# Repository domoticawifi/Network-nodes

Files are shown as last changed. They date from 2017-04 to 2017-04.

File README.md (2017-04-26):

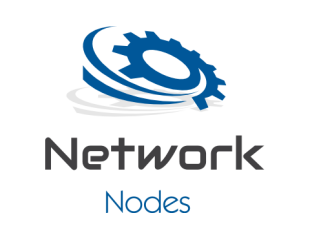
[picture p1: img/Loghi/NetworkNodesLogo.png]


Questo progetto vede la realizzazione, tramite Arduino, di una piccola rete [LAN](https://it.wikipedia.org/wiki/Local_Area_Network) (domestica o aziendale) che permette di far comunicare, attraverso un terminale PC (o qualsiasi altro device connesso alla rete), i nodi della rete; quest'ultimi collegati tra loro attraverso un collegamento ottico(infrarossi).

_____________________________________

#  Indice
* <a href="#ancora-struttura">Struttura</a>
* <a href="#ancora-comunicazioni">Comunicazioni</a>
  * <a href="#ancora-es-comunicazione">Esempio comunicazione</a>
* <a href="#ancora-schemaNet">Schema Network</a>
* <a href="#ancora-occorrente">Occorrente</a>
  * <a href="#ancora-occ-hard">Hardware</a>
  * <a href="#ancora-occ-soft">Software</a>
* <a href="#ancora-faseop">Fase Operativa</a>
  * <a href="#ancora-faseuno">1° Fase</a>
  * <a href="#ancora-fasedue">2° Fase</a>
    * <a href="#ancora-faseduemaster">Nodo Master</a>
    * <a href="#ancora-faseduenoduno">Nodo 1</a>
  * <a href="#ancora-fasetre">3° Fase</a>
    * <a href="#ancora-protuno">Primo Prototipo: Simple Connection</a>
      * <a href="#ancora-protuno-video">Video Dimostrativo Prototipo Uno</a>
    * <a href="#ancora-protdue">Secondo Prototipo: Connected Oriented</a>
        * <a href="#ancora-protdue-sol1">Soluzione "Switch Transistor"</a>
        * <a href="#ancora-protdue-sol2">Soluzione "Sensore Sferico"</a>
          * <a href="#ancora-protdue-video">Video Dimostrativo Prototipo Due</a>
* <a href="#ancora-db">Database</a>
* <a href="#ancora-app">Applicazione Android</a>
* <a href="#ancora-problemi">Problemi Rilevati</a>
* <a href="#ancora-algor">Algoritmi</a>
   * <a href="#ancora-algor-nodomaster">Nodo Master</a>
   * <a href="#ancora-algor-nodo1">Nodo 1</a>
   * <a href="#ancora-algor-nodo2">Nodo 2</a>
* <a href="#ancora-conclcost">Conclusione e Costi</a>

_____________________________________

##  Struttura



Abbiamo presvisto un terminale PC, un Nodo Master e due nodi, schematizzati in questa maniera (classifichiamo questa rete come [P2P](https://it.wikipedia.org/wiki/Peer-to-peer):
  * Terminale (Invia e riceve le informazioni dei nodi attraverso la rete accedendo all'[indirizzo IP](https://it.wikipedia.org/wiki/Indirizzo_IP) del Nodo Master)
  * [Router](https://it.wikipedia.org/wiki/Router) (Instrada le richieste fatte tra terminale e Nodo Master sulla rete domestica e anche quella esterna andando ad aggiornare un [DB](https://it.wikipedia.org/wiki/Base_di_dati))
  * Nodo Master (Nodo formato da un modulo [ESP8266 ESP-12E](https://acrobotic.com/acr-00018) per il collegamento WI-FI con il terminale, l'invio delle informazioni sul DB e la trasmissione di informazioni tra i vari nodi presenti nella rete locale).
  * Nodo1 (Nodo formato da [Arduino NANO](https://www.arduino.cc/en/Main/arduinoBoardNano) che gestisce un attuatore/relè/led e, in futuro, un eventuale sensore)
  * Nodo2(Stessa cosa del nodo precedente)
  
  *N.B: Lo storage delle informazioni su un DB, ci serve per cotrollare lo stato della rete, anche da smartphone o tablet, in         remoto (Internetworking: il router fungerà da gateway).
  Il Nodo Master può essere, a sua volta, provvisto di attuatori e sensori.
  Il problema della scheda ESP-12E è la scarsità di PIN disponibili: nel nostro caso è sato possibile collegare un solo attuatore/relè a tale nodo a differenza dei due collegati sugli altri nodi.
  La comunicazione otttica tra i nodi è di tipo punto-punto mentre quella LAN (WLAN) è di tipo [broadcast](https://it.wikipedia.org/wiki/Broadcasting_(informatica)).*
  
____________________________________________________________________________________________  
# Comunicazioni  
La comunicazione fra i nodi e il terminale avviene in questa maniera:
  * Il terminale comunica con il solo Nodo Master tramite la rete WI-FI, e riceve ed invia a questo nodo le richieste da fare agli altri due nodi della rete.
  * Il Nodo Master comunica con il terminale, via WI-FI, e, con il Nodo1, attraverso un collegamento ottico (LED IR e Sensor IR), e la stessa comunicazione avviene tra il Nodo1 e Nodo2
  * Ogni nodo può comunicare solamente con il suo nodo adiacente formando un ponte di nodi
  * Se il terminale deve contattare il Nodo2, la sua richiesta passerà prima a tutti i nodi
  
## Esempio di comunicazione: Connected Oriented

## Terminale > Nodo Master > Nodo Interessato
* Attraverso una pagina HTML, appositamente caricata in locale attraverso la scheda Wi-Fi, avremo la possibilità di inviare informazioni alla shield da qualsiasi terminale noi vogliamo (es. PC, smartphone, tablet); inoltre dalla stessa pagina sarà possibile reperire lo stato di ogni nodo(attuatori ON/OFF e sensori)
* Se volessimo inviare una certa informazione, come ad esempio l'accensione o lo spegnimento di un LED(Attuatore e/o Relè), non dovremmo far altro che selezionare l'apposito 'Radio Button' per poi determinare l'invio della Form attraverso il Bottone 'Invio'
* In questa maniera verrà mandata una richiesta tramite rete WI-FI al Nodo Master gestito dalla scheda ESP8266
* La scheda Wi-Fi riceverà la richiesta, la inoltrerà, tramite segnale infrarossi, al nodo adiacente(Nodo 1)
* Il nodo adiacente(Nodo 1) riceve questo segnale e lo elabora per capire se è lui il destinatario
* Se così non fosse lo manda all'altro nodo adiacente(Nodo 2) con il collegamento ottico
* Quando il messaggio è arrivato a destinazione, la scheda arduino presente su tale nodo spegnerà/accenderà l'attuatore o relè
* Verrà mandato, in ritorno, l'avvenuta/o accensione/spegnimento
* Il messaggio di ritorno arriverà fino al Nodo Master che darà in risposta al PC un'altra pagina HTML aggiornata
* Il Nodo Master, successivamente, manderà questo dato sul database per poterlo consultare in remoto tramite smartphone
* Il PC riceverà la pagina HTML aggiornata e vedrà lo stato attuale di tutti i nodi per una prossima operazione  
## Nodo Master > Nodo Interessato
* Il Nodo Master avrà un proprio indirizzo IP nella rete (es: 192.168.1.100)
* Il Nodo Master riceve la richiesta dal PC da instradare al giusto nodo
* Il Nodo Master comunicherà con il Nodo1, essendo il suo adiacente
* Verrà mandato un segnale ottico al Nodo1 con il dato da elaborare
* Il Nodo1 riceve questo dato e lo elabora; una volta elaborato restituisce un [ACK](https://it.wikipedia.org/wiki/ACK_(informatica)) al Nodo Master
* Il Nodo Master chiude la comunicazione
* Il Nodo1 se dovesse ricevere un dato corrotto richiede il rinvio del dato
* Il Nodo1 elabora il dato ricevuto e capisce se appartiene a lui altrimenti lo manda, alla stessa maniera della prima comunicazione, al nodo adiacente (Nodo2)
* Così come il Nodo1 ha elaborato il dato all'andata, il Nodo Master lo farà per il ritorno
* Una volta chiusa la comunicazione il Nodo Master aggiorna la pagina HTML e comunica il cambiamento al database

*N.B: Se non dovesse esserci instradamento in uscita(connessione internet) sulla rete LAN, la connessione tra i nodi non ne risentirebbe e continuerebbe ad operare. Il database verrà aggiornato appena sarà presente una connessione in uscita.
Per verificare lo stato di ogni nodo, si è pensato di collegare un Display LCD o OLED. Su questo display compariranno le azioni che sta eseguendo tale nodo. Esempio: Nodo1 - Display (Sto comunicando...) -> Nodo2 - Display (Sto ricevendo...)*

___________________________________________________________________________________
# Schema Network
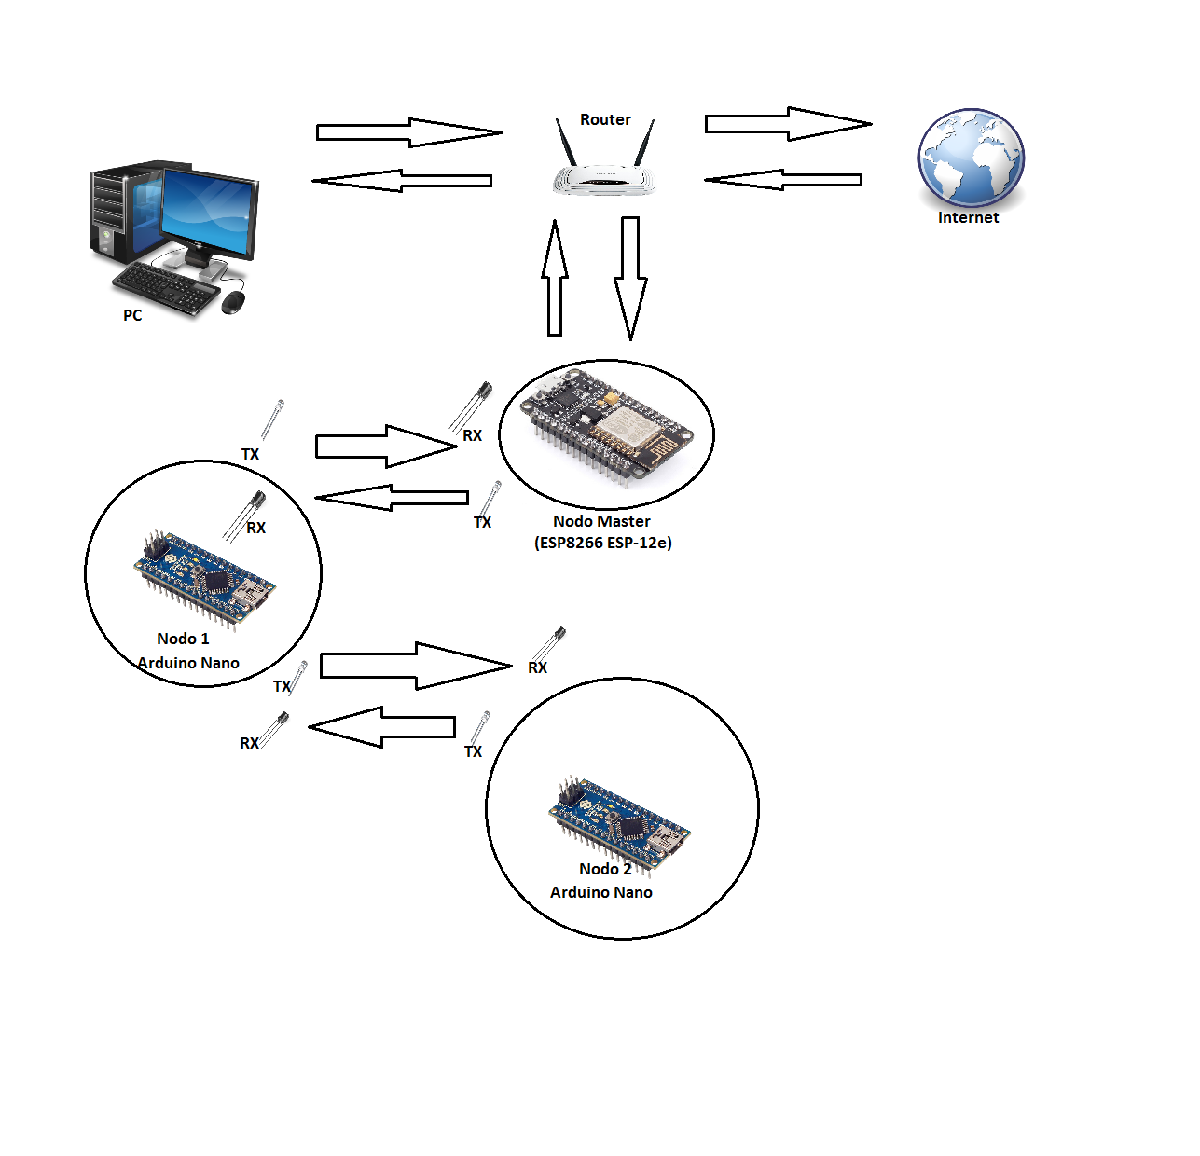
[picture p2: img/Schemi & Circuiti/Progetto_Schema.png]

Come possiamo vedere dall'immagine, abbiamo un PC che funziona da terminale:collegato alla rete WI-FI, invia e riceve informazioni attraverso il Nodo Master.
Il Nodo Master, collegato alla rete, instrada le richieste e le informazioni, mandate dal terminale e dagli altri nodi, nella giusta direzione.

## Occorrente Hardware
  * 1 terminale (PC, Tablet, Smartphone)
  * 1 Router WI-FI
  * 1 ESP8266 ESP-12E oppure una qualsiasi shield WI-FI
  * 2 Arduino NANO/UNO/MEGA/Mino PRO
  * 4 TX Diodo LED infrarossi
  * 4 RX Sensori IR
  * 3 Breadboard (830 fori)
  * Cavetti e jumper per i collegamenti
  * 3 Display LCD per verificare lo stato di ogni nodo
  * 4 pulsanti
  
## Occorrente Software
  * [Arduino IDE 1.8.0](https://www.arduino.cc/en/main/software) o superiori
  * [Firebase](https://firebase.google.com/)
  * [Core ESP8266](https://github.com/domoticawifi/Network-nodes/blob/master/GestioneShieldESP8266.md)
  * [Librearia gestione ESP8266](https://github.com/googlesamples/firebase-arduino/archive/master.zip)
  * [Libreria gestione segnale IR](https://www.pjrc.com/teensy/arduino_libraries/IRremote.zip)
  * [Libreria gestione Display LCD](https://www.dropbox.com/s/62x4w48kwf5biko/LiquidCrystalI2C.zip?dl=0)
  
Per l'installazione e la gestione delle librerie clicca [QUI](https://github.com/domoticawifi/Network-nodes/blob/master/Library/GestioneLibraryArduino.md)

________________________________________________________________________________________  
  
# Fase Operativa

 ## Prima fase: Collegamento Scheda WI-FI ad una rete LAN 
 
 
 
 Potete vedere la connessione Wi-Fi della shield cliccando <a href="https://github.com/domoticawifi/Network-nodes/blob/master/GestioneShieldESP8266.md#ancora-collegamento-wifi">QUI</a>.
 
 * Una volta testata la connessione di questa shield, si è implementata un'interfaccia grafica in HTML per comunicare i cambiamenti di stati di alcuni attuatori e relè presenti sul Nodo Master (attuatori e relè sono sostituiti da semplici led per facilitare i collegamenti, ma il concetto non cambia).
 * La pagina HTML viene mandata al terminale dalla scheda ESP8266 e aggiornata ogni qual volta avviene un cambiamento di stato dettato dal terminale.
 * Il cambiamento di stato avviene attraverso una semplice FORM HTML che invia i dati cambiati all'URL della pagina.
 Ecco la pagina HTML con la relativa Form:
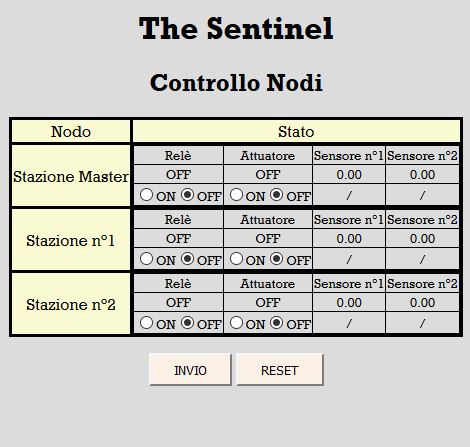
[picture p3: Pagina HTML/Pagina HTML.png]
 
 
*N.B:La pagina HTML ha tutte le funzionalità! Ma di queste solo l'accensione del relè e dell'attuatore sul Nodo Master funziona! Il resto verrà implementato man mano...*
 
 * Il terminale, per accedere a tale pagina HTML, dovrà allocarsi, tramite browser(Chrome, Firefox, Edge, ....) all'indirizzo IP associato alla shield Wi-Fi.
 * Tale indirizzo sarà visualizzato su terminale, per le prime prove, e, in un secondo momento, su un display posizionato sul nodo.
 * Il programma di lancio lo trovate [Qui](https://github.com/domoticawifi/Network-nodes/blob/master/Sketch/Sketch%20Di%20Prova/sketch_SchedaWiFi_NodoMaster_Prova_AccensioneLED.ino).
 
Ecco i collegamenti:
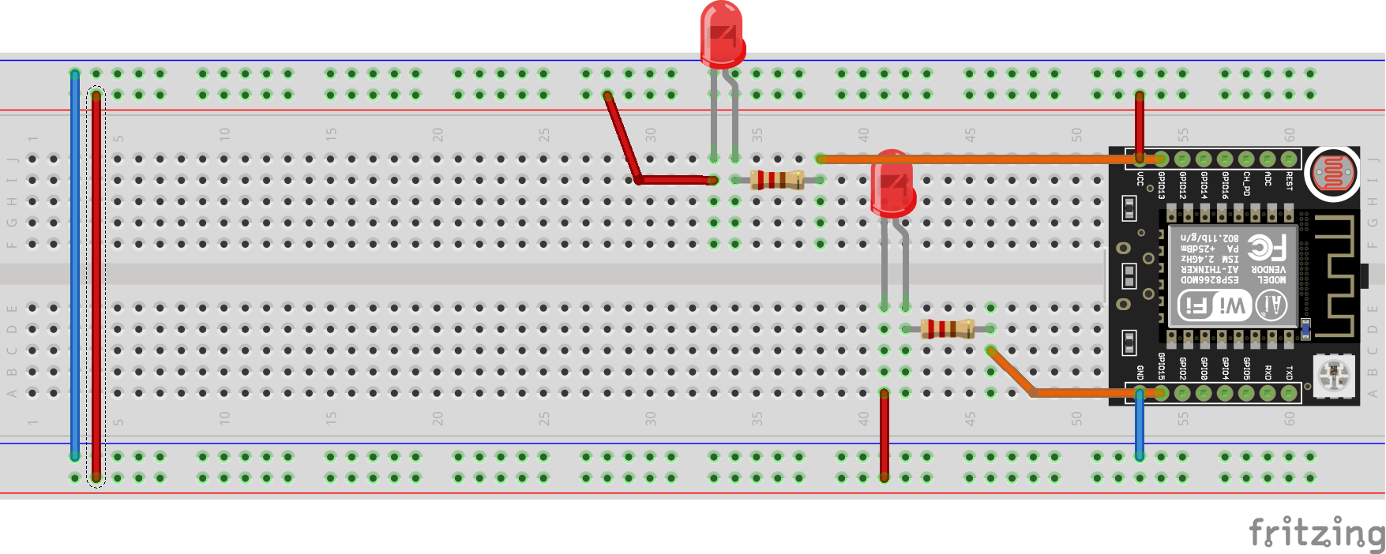
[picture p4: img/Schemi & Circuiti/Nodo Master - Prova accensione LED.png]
 
 Su Fritzing non è presente l'ESP-12E compreso di basetta per i collegamenti e USB incorporata, ma una semplice ESP-12E.
 Con un pò di fantasia immaginiamo che questa scheda sia quella che stiamo utilizzando noi(la scheda con 30 pin), per facilitarne la spiegazione.
 
 I due collegamenti che vanno ai led sono i pin D1 e D2.
 
 *N.B: Nella seconda fase lasceremo solo un led che rappresenterà un solo relè/attuatore, perchè abbiamo poca disponibilità di piedini nella ESP-12E. In questo caso il led sarà collegato al piedino D4; i piedini D1 e D2 saranno riservati al display lcd I2C.*
 
 Ecco una foto dei collegamenti su breadbord:
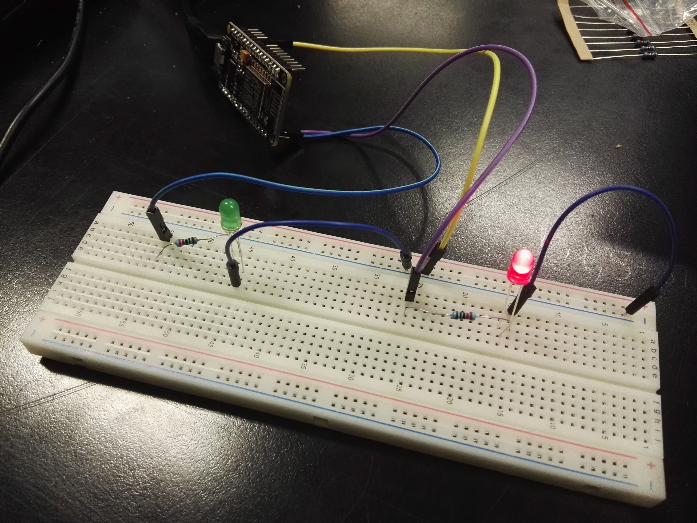
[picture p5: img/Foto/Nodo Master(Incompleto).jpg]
 
 Purtroppo la shield Wi-Fi ha una larghezza che va ha coprire tutta la breadbord e per facilitare i collegamneti abbiamo utilizzato dei jumper.
 Dalla foto risulta acceso il led 2, questo perchè abbiamo attivato, attraverso la pagina HTML visualizzata dal PC, l'accensione del led 2(Che rappresenta un semplice relè).

 Fatto questo possiamo passare ad aggiungere una coppia di LED infrarossi-Ricevitore IR, per la comunicazione ottica con il Nodo 1.

 *N.B: Possiamo anche non utilizzare i resistori, perchè la tensione di uscita sui pin non supera i 3volt.*

 ## Seconda fase: Collegamento Ottico Nodo Master -> Nodo 1 
 
 Per questa fase, avremo la comunicazione fra due nodi, quindi dividiamola, per semplicità, in due sotto-fasi.
 
 ### *Nodo Master: Collegamento Ottico*
 Lo schema che andremo a realizzare sarà il seguente:
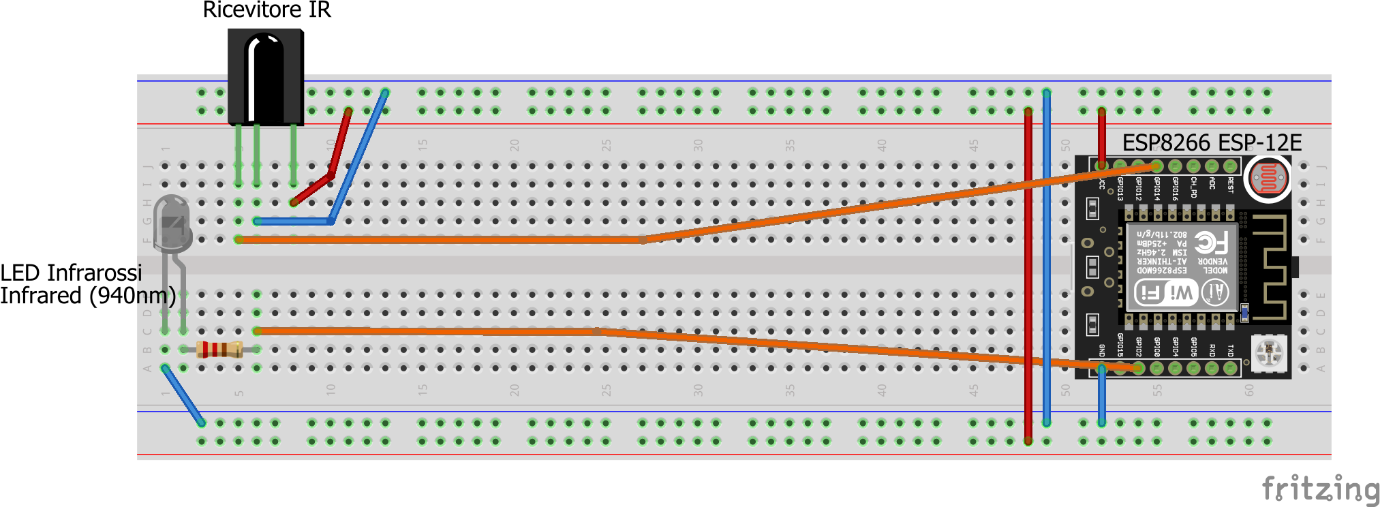
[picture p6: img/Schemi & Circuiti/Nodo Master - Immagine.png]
 
 
 Tale schema dovrà essere incorporato con lo schema della prima fase; così facendo avremmo il nostro Nodo Master completo!
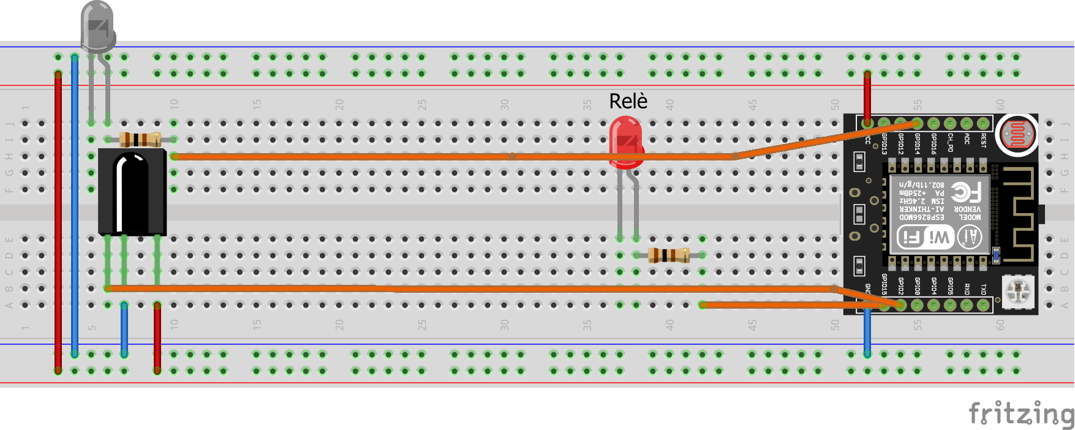
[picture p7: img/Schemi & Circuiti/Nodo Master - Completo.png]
 
 
 I collegamenti sono i seguenti:
 <table align='center'>
  <tr align='center'>
   <td> </td>
   <td>DISPLAY</td>
   <td>LED</td>
   <td>EMETTITORE IR</td>
   <td>RICEVITORE IR</td>
  </tr>
  <tr align='center'>
   <td>ESP8266</td>
   <td>D1, D2</td>
   <td>D4</td>
   <td>D0</td>
   <td>D3</td>
   </tr>
 </table>
 
 Così facendo occuperemo tutti i pin disponibili.
 Purtroppo ESP-12E non ha tanti pin da poter essere utilizzati, perchè gli altri sono tutti gestiti dalla scheda stessa.
  
 Per connettere la scheda al display LCD, vi rimando a [questa pagina](https://www.losant.com/blog/how-to-connect-lcd-esp8266-nodemcu).
 
 *N.B: Possiamo anche non utilizzare i resistori, perchè la tensione di uscita sui pin non supera i 3volt. Se dovessimo usare resistenze alte la luce risulterebbe più fievole, comportando un possibile ostacolo alla comunicazione*
 
 *Durante i collegamneti e i test abbiamo riscontrato un problema! Non sappiamo a cosa sia dovuto, ma se dovessimo alimentare il sensore IR con i 5v della shield Wi-Fi, i dati risulterebbero molto corrotti! Utilizzando l'alimentazione di Arduino i risultati sono migliori... comunque abbiamo dei piccoli problemi, dovuti a disturbi e alla scarsa schermatura, nel rilevare il valore dal sensore. Spiegheremo questo più avanti...*

 Da aggiungere all'occorrente software, per la realizzazione del Nodo Master, è la libreria per la gestione dei segnali infrarossi per la shield ESP8266 (purtroppo non può essere utilizzata la stessa libreria di arduino!).
 Possiamo scaricarla da [qui](https://github.com/markszabo/IRremoteESP8266/), dove è presente una piccola guida per l'installazione.

 ### *Nodo 1: Collegamento Ottico*
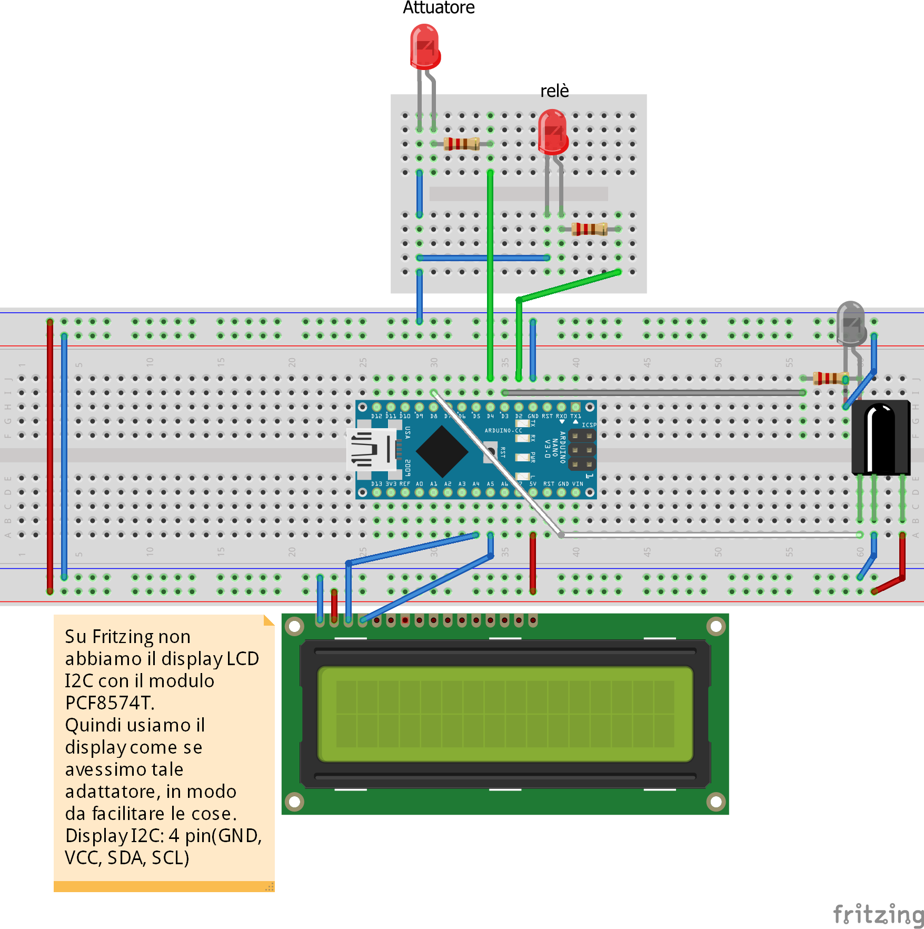
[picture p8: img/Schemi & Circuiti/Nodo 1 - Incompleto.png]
 
 
 *N.B:Può essere usato, tranquillamente, Arduino UNO! Arduino Nano è esattamente uguale(tranne nella dimensione) ad Arduino UNO! Noi per le prove abbiamo utilizzato Arduino UNO per comodità...*
 
 Connessioni:
 
 <table>
 <tr align='center'>
  <td>Arduino UNO/NANO</td>
  <td> </td>
 </tr>
 <tr>
  <td>PIN 2</td>
  <td>Relè</td>
 </tr>
 <tr>
  <td>PIN 3 </td>
  <td>Emettitore LED IR</td>
 </tr>
 <tr>
  <td>PIN 4 </td>
  <td>Attuatore</td>
 </tr>
 <tr>
  <td>PIN 8 </td>
  <td>Ricevitore IR</td>
 </tr>
 <tr>
  <td>PIN A4 </td>
  <td>Display SDA</td>
 </tr>
 <tr>
  <td>PIN A5 </td>
  <td>Display SCL</td>
 </tr>
 <tr>
  <td>5v </td>
  <td>Breadboard</td>
 </tr>
 <tr>
  <td>GND </td>
  <td>Breadboard</td>
 </tr>
</table>

Il collegamento dell'emettitore IR è obbligatorio farlo sul PIN3! Perchè la libreria di Arduino sull'invio del segnare infrarosso utilizza quel piedino per default. Se volessimo cambiare piedino dovremmo andare ad agire sulla libreria.

 Per le prime prove, si è installato, sui due nodi, un emettitore(sul Nodo Master) e un sensore infrarossi(sul Nodo 1), per un semplice test di comunicazione.
 Si è inviato un piccolo dato, sottoforma di codifica NEC, dal Nodo Master al Nodo 1. Si hanno a disposizione tanti tipi di codifica: NEC, Sony, Sharp e tante altre...
 
 Nel nostro caso, ogni nodo avrà almeno una coppia led-sensore per l'invio e ricezione infrarossi, quindi il procedimento è più complesso.
 Il punto che va a favore è che si conosce il dato che potrebbe arrivare, questo perchè possono verificarsi solo queste situazioni:
 * Attivazione Relè Nodo 1;
 * Attivazione Attuatore Nodo 1;
 * Attivazione Relè Nodo 2;
 * Attivazione Attuatore Nodo 2.
 
Quindi i segnali che possono essere inoltrati dall'emettitore IR(sul Nodo Master) sono essenzialmente 4; a questi c'è da aggiungere un solo segnale di ritorno(Nodo 1, Nodo 2) che verifica la corretta ricezione del dato.

Procediamo per gradi...

* Il Nodo 1 riceve un dato dal Nodo Master attraverso la comunicazione infrarossi;
* Il Nodo Master, una volta inviato il dato, rimane in ascolto per l'ok(ACK);
* Il Nodo 1 elabora tale dato e verifica se può usarlo;
* Se può usarlo, lo elabora ed esegue un comando. Fatto questo manda l'ok al Nodo Master;
* Se non può usarlo manda al Nodo Master un dato per il rinvio del dato(il dato potrebbe essere corrotto);
* Il Nodo Master, in base alla risposta del Nodo 1, ritrasmette il dato oppure chiude la comunicazione.

Tutto questo dovrà essere implementato con un elegante e bell'algoritmo. 



Questo è l'algoritmo che dovrà eseguire il Nodo Master una volta inviato il dato.
Il Nodo 1 dovrè elaborare il dato inviato e mandargli la conferma.



*N.B: Se dovesse passare un certo lasso di tempo(es. 10 secondi) la comunicazione si interrompe!*

Una volta eseguiti tutti i collegamenti, possiamo eseguire gli sketch dei due nodi:
* [Programma Nodo Master](https://github.com/domoticawifi/Network-nodes/blob/master/Sketch/Sketch%20Definitivi/Nodo%20Master(Comunicazione%201%20Nodo).ino)
* [Programma Nodo 1](https://github.com/domoticawifi/Network-nodes/blob/master/Sketch/Sketch%20Definitivi/Nodo%201%20-%20Comunicazione%201%20Nodo.ino)

*N.B: Questi due programmi sono per la comunicazione fra Nodo Master e Nodo 1. Se dovessimo collegare un altro nodo(come faremo più in la) i due programmi cambieranno(cambierà solo il programma del Nodo 1).*

Con il lancio di questi due programmi otteniamo il risultato voluto:
* Il client si connette all'indirizzo IP della scheda wi-fi;
* Decide di cambiare lo stato di un attuatore e/o relè sul Nodo 1; 
* Il Nodo Master riceve il dato inviato e lo elabora inviandolo al Nodo 1;
* Il Nodo 1 elabora il dato ricevuto; in questa fase il Nodo Master rimane in ascolto per 10 secondi;
* Il Nodo 1, se accetta il dato, manda un ACK al Nodo Master;
* Il Nodo Master riceve l'ok è chiude la comunicazione aggiornando la pagina HTML che visualizzerà il client.

Il compito del Nodo Master è quello di un server web e di un "Ponte di comunicazione" tra il terminale e gli altri nodi.

*N.B: Potrebbe capitare che:*
* *La comunicazione sia interrotta da un ostacolo:in questo caso il Nodo Master invia per 10 secondi lo stesso dato fino a che non riceverà conferma. Se non dovesse ricevere conferma chiude comunicazione e la pagina HTML non viene aggiornata*
* *La comunicazione viene interrotta solo dopo che il Nodo 1 ha ricevuto il dato corretto(in questo caso non potrà comunicare l'ok):*
*Potremmo risolvere questo problema mandando in ritorno una pagina con un WARNING di comunicazione attraverso un javascript.
Purtroppo non possiamo prevenire ostacoli durante la comunicazione, ma su 100 comunicazione provate, solamente un 10%, non ha ricevuto l'ACK dal Nodo 1!
Mandando il WARNING il client sa che qualcosa non è andato nel modo giusto, perchè potrebbe risultare anche un guasto a qualche componente di comunicazione.
Questo problema potrebbe essere in parte gestito...
Si è pensato di mandare, attraverso il Nodo Master, lo stato precedente del dato che non è stato ricevuto; così facendo si ha la sicurezza, in parte, di far tornare il Nodo 1 allo stato precedente. Questo è possibile se e solo se la comunicazione è interrotta solo nella ricezione della risposta e non nell'invio del dato!*

*PS:
Durante la fase di ascolto del Nodo Master, il Nodo 1 manda un ACK per circa 10 secondi; nei dieci secondi di ascolto, da parte del Nodo Master, vengono prelevati valori random non inviati dal Nodo 1. 
Fortunatamente, nell'arco dei 10 secondi di ascolto, il dato, inviato dal Nodo 1, viene letto dal Nodo Master ricevendo l'ok di avvenuta ricezione.*

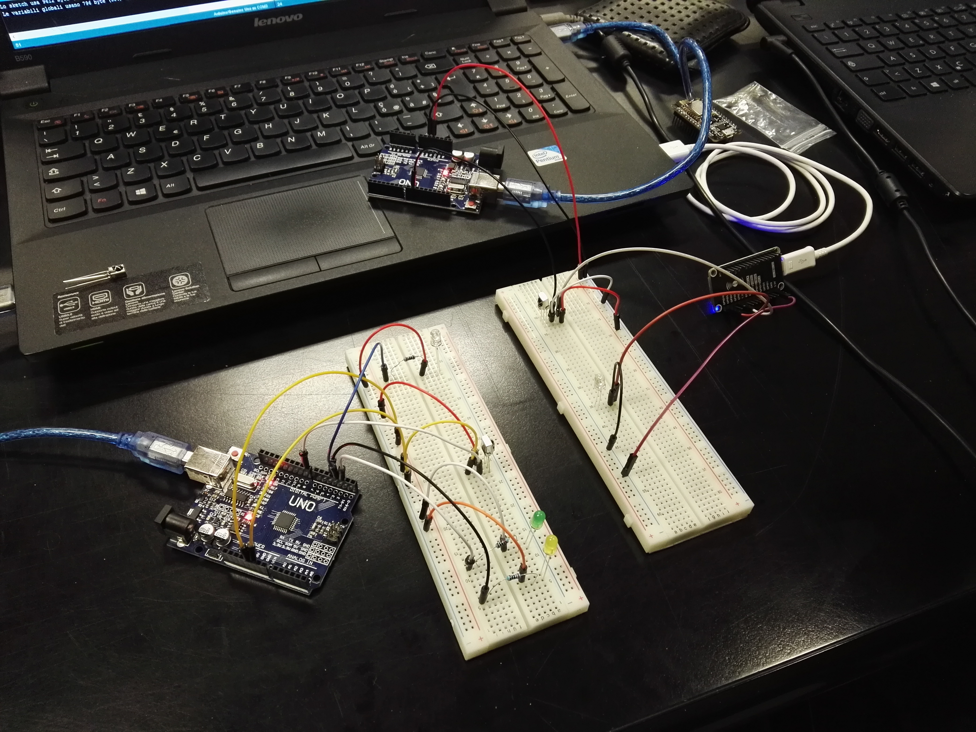
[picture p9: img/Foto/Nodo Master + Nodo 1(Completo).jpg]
</a>

Come dicevamo in precedenza: il terzo arduino serve solo per alimentare il ricevitore del Nodo Master e in secondo a prelevare i valori del sensore, solamente per essere testati.

Il ricevitore IR, del Nodo Master, ci ha dato parecchi problemi:
* I valori rilevati erano falsati(riceveva valori anche quando non venivano inviati segnali infrarossi)
* L'alimentazione della shield Wi-Fi dava parecchi problemi al sensore durante la lettura

##### *Come si è risolto tutto ciò?*
Si è utilizzata, prima di tutto, un'alimentazione esterna, presa da un altro Arduino UNO (l'alimentazione può essere presa anche da una pila esterna), risolvendo in parte i problemi di lettura del sensore; in questo modo parte del primo problema è stata risolta, ma tuttavia continua, in modo random, a ricevere valori casuali.
Non si è venuto a capo di questo!!!
Si è cercato di risolvere la cosa nel migliore dei modi: Potrebbe essere un problema della scheda, un problema del sensore, un problema di alimentazione... Potrebbe essere tutto o niente... 

*N.B: potrebbe capitare che il dato inviato dal Nodo 1 non venga letto del sensore del Nodo Master, ma su 100 prove non è mai successo! Il dato prima o poi verrà letto!*

 ## Terza fase: Collegamento Ottico Nodo Master -> Nodo 1 -> Nodo 2
 Per questa terza fase implementiamo due prototipi:il primo avrà una semplice comunicazione senza risposta del Nodo 2(cioè senza verificare la ricezione del dato), mentre il secondo sarà quello più completo e strutturato in cui anche il Nodo 2 interagisce attraverso l'architettura "Connected Oriented" sfruttata già dagli altri due nodi.
 
 ### *Primo prototipo: Simple Connection*
 * Lo schema per il Nodo Master rimane lo stesso, senza nessuna variazione neanche nel codice(essendo già tutta implementata)
 * Lo schema del Nodo 1 subische piccolissime variazioni(un'aggiunta di un solo LED infrarossi e due pulsanti per l'accensione dei dispositivi):
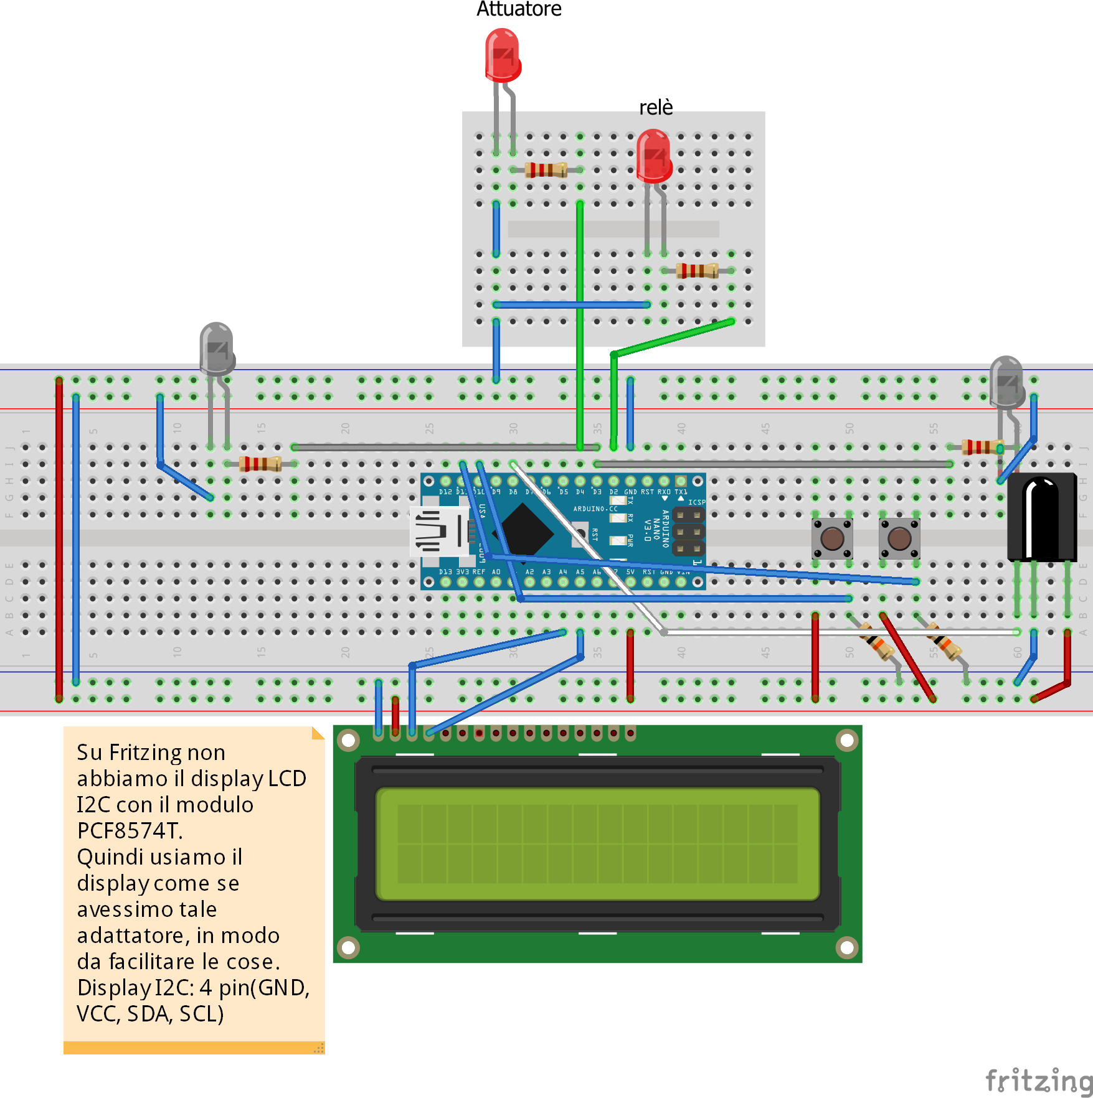
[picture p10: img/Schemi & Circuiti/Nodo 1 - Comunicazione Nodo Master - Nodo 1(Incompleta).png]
 
 
Si è semplicemente aggiunto un altro diodo led infrarossi per inviare il segnale al Nodo 2.
In questo caso abbiamo il LED IR aggiuntivo collegato allo stesso piedino del primo LED IR(in modo da sfruttare la libreria per l'invio del segnale IR, questo perchè, come dicevamo, la libreria IRremote utilizza, per default, il PIN3 di arduino).
Il codice sorgente è leggermente diverso rispetto al primo.
Lo sketch lo trovate [qui](https://github.com/domoticawifi/Network-nodes/blob/master/Sketch/Sketch%20Definitivi/Nodo_1%20-%20Comunicazione%20Nodo%20Master%20e%20Nodo%201.ino).

Si sono aggiunti due pulsanti per controllare, in modo analogico, lo stato dei sispositivi collegati al Nodo 1.
Una volta avvenuto il cambiamento viene comunicato lo stato al Nodo Master.

* Lo schema del Nodo 2 è il seguente:
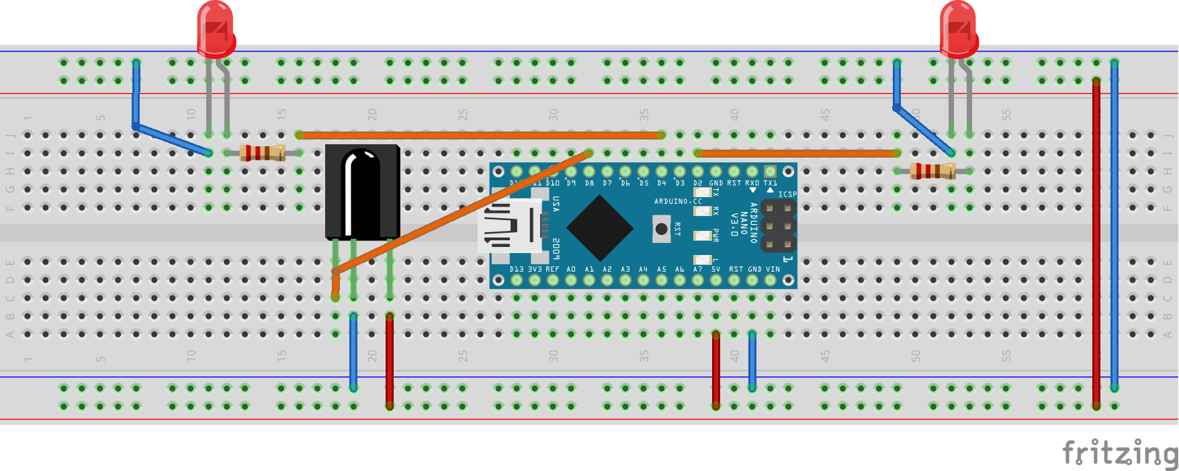
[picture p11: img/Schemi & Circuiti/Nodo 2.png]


I collegamenti:
<table>
 <tr>
 <td>Arduino NANO</td>
 <td> </td>
 </tr>
 <tr>
 <td>PIN 2</td>
 <td>LED(Relay)</td>
 </tr>
 <tr>
 <td>PIN 4</td>
 <td>LED(Attuatore)</td>
 </tr>
 <tr>
 <td>PIN 8</td>
 <td>Ricevitore IR</td> 
 </tr>
 <tr>
 <td>PIN A4</td>
 <td>Display SDA</td> 
 </tr>
 <tr>
 <td>PIN A5</td>
 <td>Display SCL</td> 
 </tr>
</table>

Lo sketch da far eseguire a questa scheda è il [seguente](https://github.com/domoticawifi/Network-nodes/blob/master/Sketch/Sketch%20Definitivi/Nodo_2%20-%20Incompleto.ino)

La disposizione dei tre nodi è il seguente:
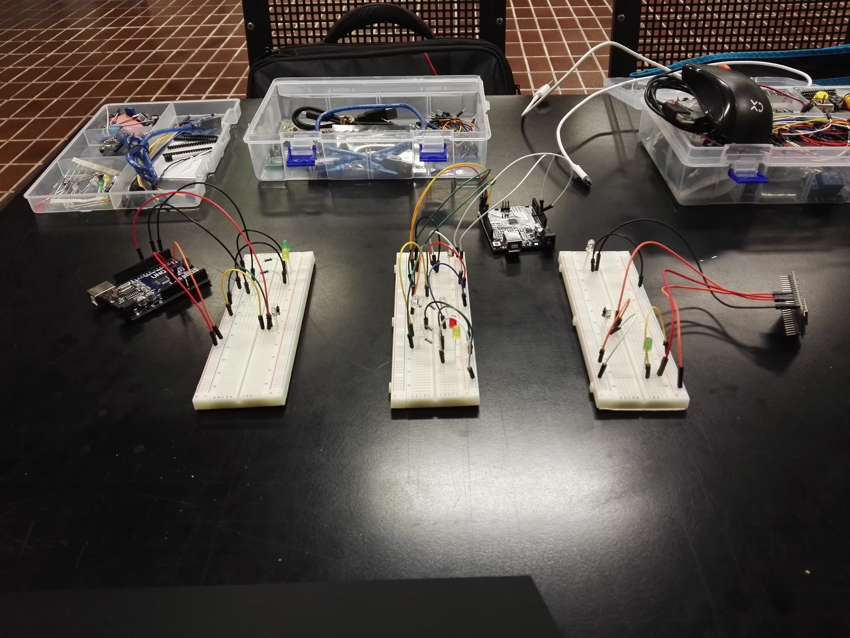
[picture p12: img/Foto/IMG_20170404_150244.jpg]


Da destra verso sinistra: Nodo Master(con modulo ESP8266), Nodo 1(con Arduino UNO), Nodo 2(con Arduino UNO).

*N.B: In questo caso la comunicazione, per attivare attuatori e relè sul Nodo 2 è del tipo semplice... cioè senza ack. Non si è ancora implementata una Connected Oriented tra Nodo 1 e Nodo 2.*

#### *Video*

<table align='center'>
  <tr align='center'>
   <td>Video </td>
   <td>Link</td>
  </tr>
  <tr align='center'>
   <td>Promo</td>
   <td>https://youtu.be/ombGCsYmXGk</td>
   </tr>
   <tr align='center'>
   <td>Completo</td>
   <td>https://youtu.be/g6Z9CRAygbg</td>
   </tr>
 </table>
 
________________________________________________________ 

### *Secondo prototipo: Connected Oriented*

Per il secondo prototipo si devono apportare delle piccole modifiche:
* Modificare lo sketch del Nodo Master;
* Modificare lo schema e lo sketch del Nodo 1;
* Modificare lo schema e lo sketch del Nodo 2.

Per il primo prototipo non era richiesta la risposta dell'avvenuta ricezione del dato da parte del Nodo 2, mentre in questo prototipo vogliamo instaurare un "dialogo" tra Nodo 1 e Nodo 2, così come quello che avviene tra gli altri due nodi.
Per far ciò dobbiamo collegare un altro sensore infrarosso, questa volta rivolto verso il Nodo 2, in modo da captare le frequenze infrarosse di quest'ultimo.
Questo purtroppo non è possibile! Arduino non riesce a gestire due sensori IR perchè nella parte di programmazione non è possibile creare due oggetti(o istanze) di due diversi sensori con la stessa classe!
Questo descritto è un problema in ambito di programmazione ma si è pensato a delle possibili soluzioni:
* Un sensore IR sferico(360°) in modo da poter coprire, interamente, entrambi i nodi; risulterebbero dei problemi nella ricezione, perchè riceverà da entrambi i versi, ma logicamente potrebbe funzionare;
* Una serie di specchi che converge il fascio del segnale infrarossi del Nodo 2 verso il sensore del Nodo 1; potrebbe sembrare fantascienza ma potremmo usare lo stesso principio dei telescopi;
* Per ultimo, ma non meno importante, la "triangolazione".

*Cos'è la "triangolazione"?*

*Con triangolazione intendiamo la disposizione dei nodi a formare un triangolo.
Come in questa figura:*

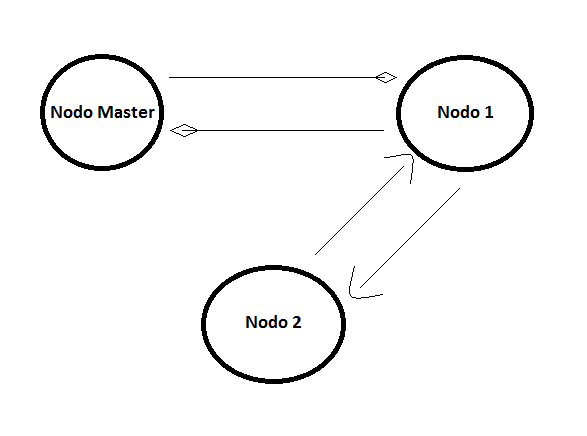
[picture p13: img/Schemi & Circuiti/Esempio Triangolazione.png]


*Così facendo i nodi sono disposti in modo tale da poter inviare al Nodo 1 i segnali infrarossi.*

Logicamente è una disposizione corretta da realizzare, ma facendo alcune prove e test si è verificato che questa comunicazione non può avvenire!
Il sensore del Nodo 1 è soggetto a troppe informazione e non riesce a captare nel modo corretto il segnale di ritorno del Nodo 2.
Si è pensato ad un altro tipo di soluzione, da aggiungere alle altre elencate poco fa:
* Gestire il cambio di sensore attraverso un circuito switch a transistor: due transistor per alimentare due diversi circuiti, in modo alternato, in base alla ricezione del dato(*soluzione hardware*).

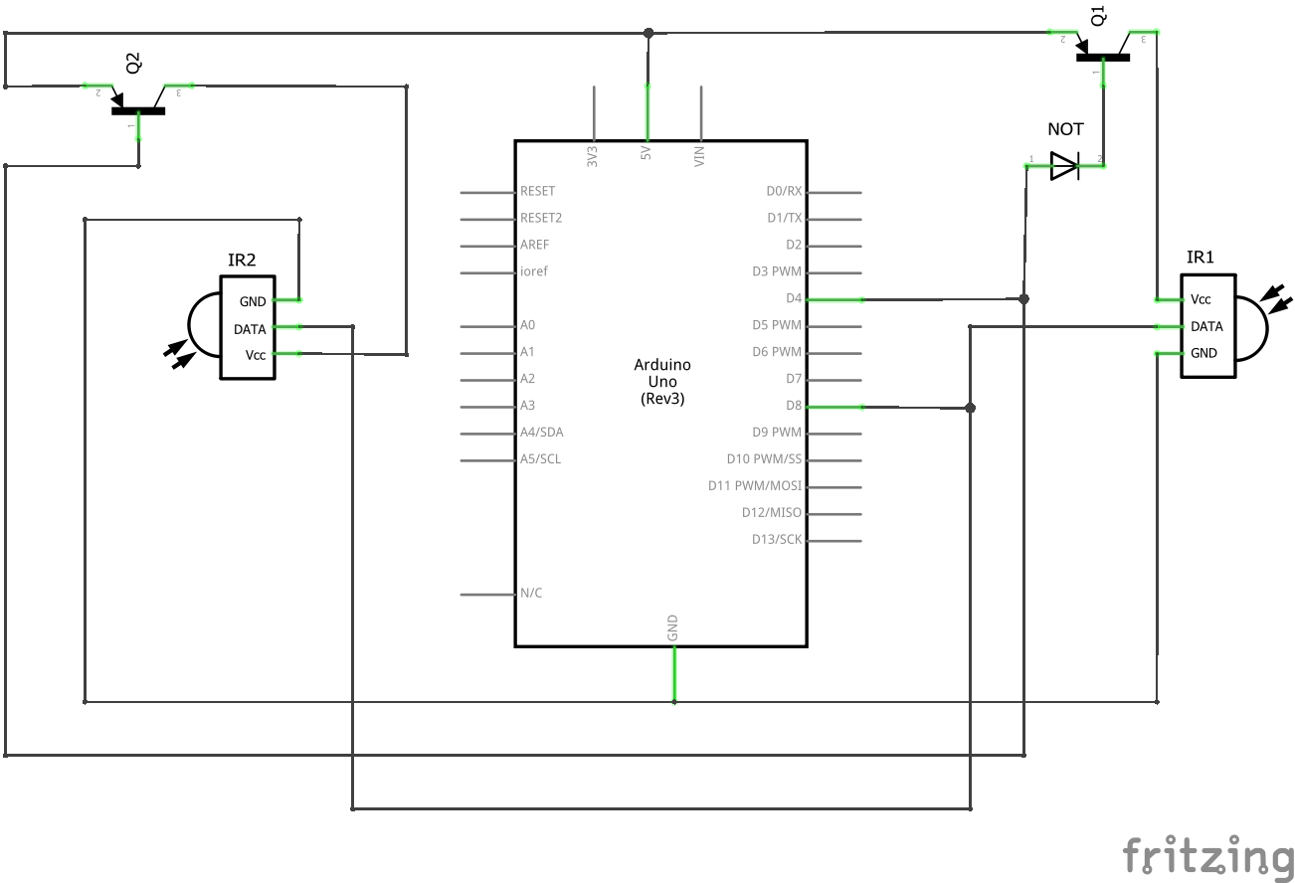
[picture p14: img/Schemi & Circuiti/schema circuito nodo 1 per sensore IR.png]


*N.B: Questo potrebbe essere realizzato anche con un semplice relè! Basta collegare uno dei due sensori all'ingresso "Normalemente chiuso" e lìaltro al "Normalmente aperto" del relè... In modo che solo uno dei due sensori è in funzione!*

Si potrebbe progettare un "Secondo prototipo" con tutti i metodi risolutivi elencati e constatare quanti e quali di questi metodi funzionino...
In questo caso realizzeremo l'ultimo metodo risolutivo:

### *Risoluzione con "Switch a transistor":*
Per quanto questo metodo possa essere logicamente corretto purtroppo non può essere realizzato!
Perchè non è possibile collegare, allo stesso pin di Arduino, i due pin dei sensori che trasportano il segnale... Quando uno dei due sensori è interdetto l'altro sensore non percepisce nessun dato... Come se il circuito fosse aperto!

### *Risoluzione con "Sensore Sferico" su Nodo 1:*
Per questo tipo di risoluzione non abbiamo utilizzato un sensore sferico, ma ne abbiamo utilizzati due direzionali:
uno rivolto verso il Nodo Master e l'altro verso il Nodo 2.
In questo modo si ha una copertura totale della ricezione dei segnali provenienti da entrambe le direzioni.

Ecco i tre nodi completi:

#### *Nodo Master*
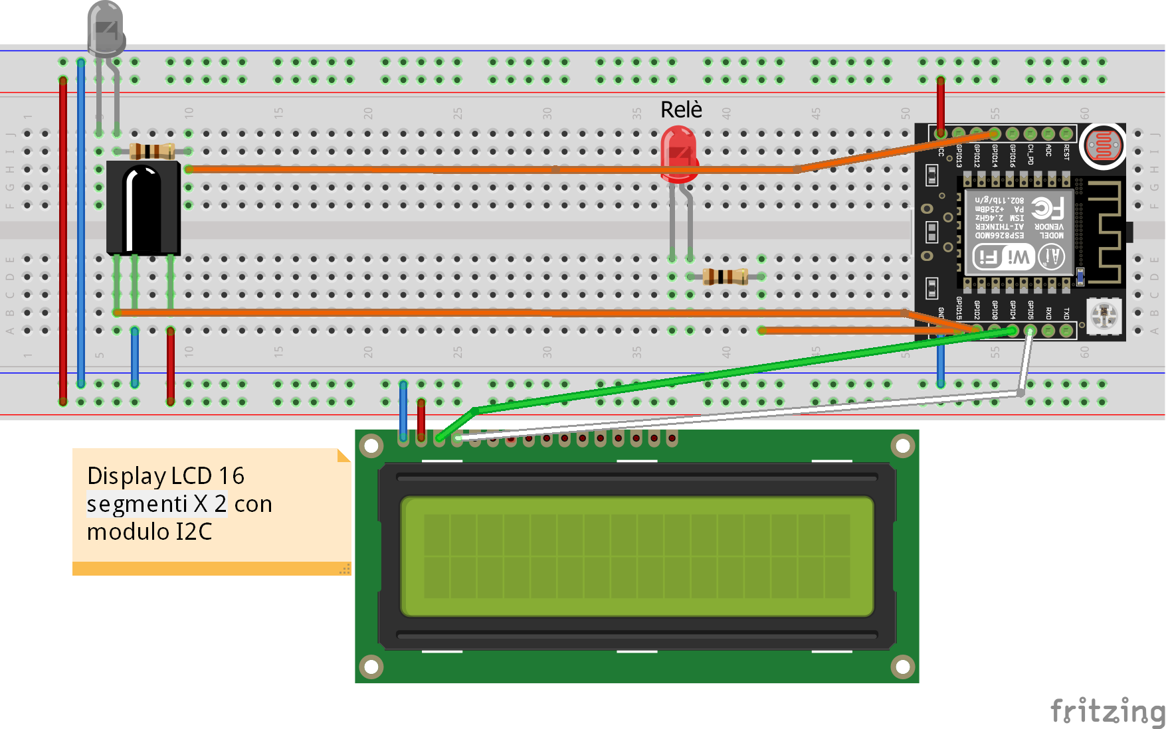
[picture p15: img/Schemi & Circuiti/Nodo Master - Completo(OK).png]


[Sketch Nodo Master](https://github.com/domoticawifi/Network-nodes/tree/master/Sketch/Sketch%20Definitivi/COMPLETO/Nodo_Master)

Connessioni:
 
 <table>
 <tr align='center'>
  <td>ESP8266</td>
  <td> </td>
 </tr>
 <tr>
  <td>PIN D4</td>
  <td>Relè</td>
 </tr>
 <tr>
  <td>PIN D0 </td>
  <td>Emettitore LED IR</td>
 </tr>
 <tr>
  <td>PIN D3 </td>
  <td>Ricevitore IR</td>
 </tr>
 <tr>
  <td>PIN D1 </td>
  <td>Display SDA</td>
 </tr>
 <tr>
  <td>PIN D2 </td>
  <td>Display SCL</td>
 </tr>
</table>

_____________________________________________________

#### *Nodo 1*
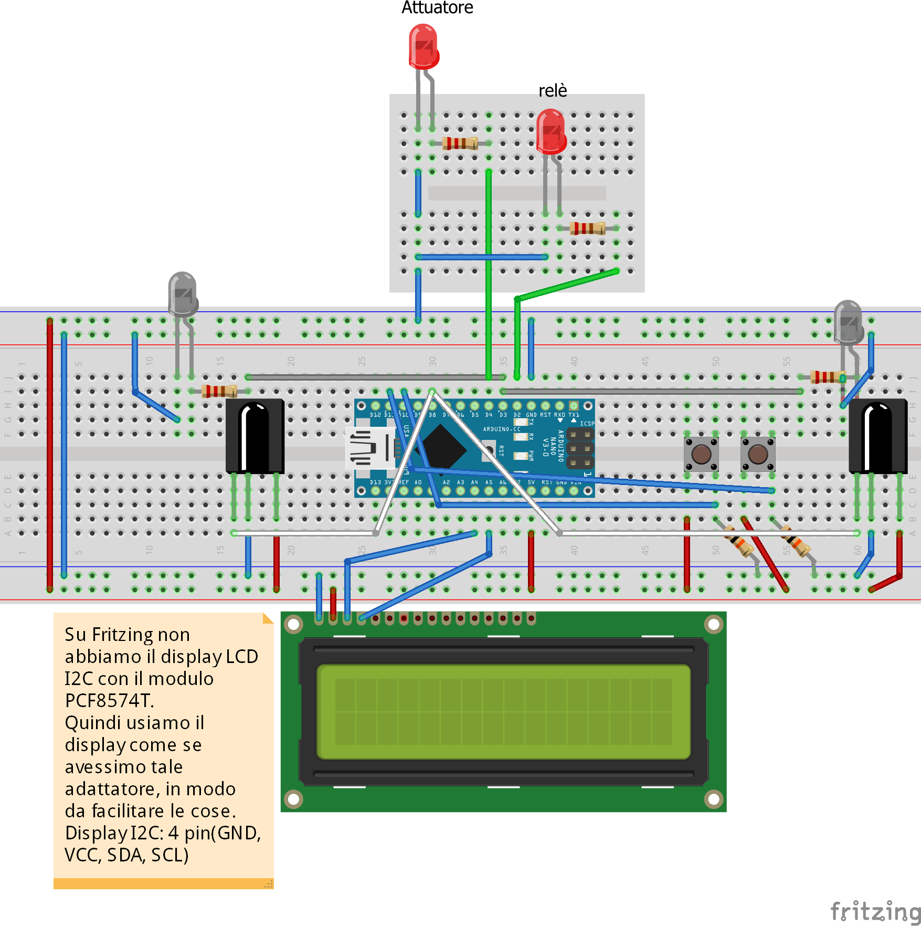
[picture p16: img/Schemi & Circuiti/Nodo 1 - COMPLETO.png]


[Sketch Nodo 1](https://github.com/domoticawifi/Network-nodes/tree/master/Sketch/Sketch%20Definitivi/COMPLETO/Nodo_1)

Connessioni:
 
 <table>
 <tr align='center'>
  <td>Arduino UNO/NANO</td>
  <td> </td>
 </tr>
 <tr>
  <td>PIN 2</td>
  <td>Relè</td>
 </tr>
 <tr>
  <td>PIN 3 </td>
  <td>Emettitore LED IR/LED IR2</td>
 </tr>
 <tr>
  <td>PIN 4 </td>
  <td>Attuatore</td>
 </tr>
 <tr>
  <td>PIN 8 </td>
  <td>Ricevitore IR/Ricev. IR2</td>
 </tr>
 <tr>
  <td>PIN A4 </td>
  <td>Display SDA</td>
 </tr>
 <tr>
  <td>PIN A5 </td>
  <td>Display SCL</td>
 </tr>
 <tr>
 <tr>
  <td>PIN 10 </td>
  <td>Pulsante Relay</td>
 </tr>
 <tr>
  <td>PIN 11 </td>
  <td>Pulsante Attuatore</td>
 </tr>
 <tr>
 <tr>
  <td>5v </td>
  <td>Breadboard</td>
 </tr>
 <tr>
  <td>GND </td>
  <td>Breadboard</td>
 </tr>
</table>

______________________________________________________

#### *Nodo 2*
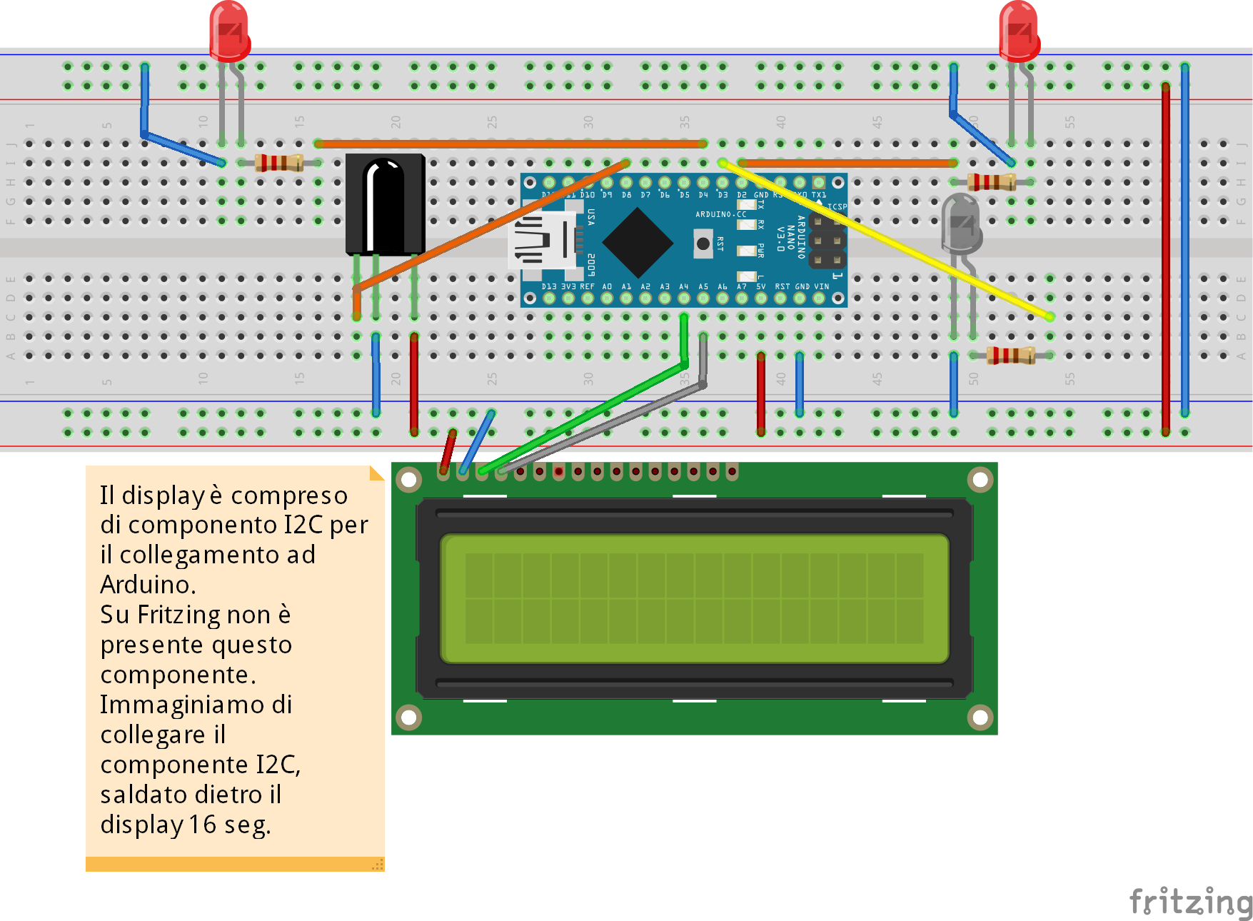
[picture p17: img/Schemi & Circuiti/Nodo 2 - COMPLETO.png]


[Sketch Nodo 2](https://github.com/domoticawifi/Network-nodes/tree/master/Sketch/Sketch%20Definitivi/COMPLETO/Nodo_2)

Connessioni:
 
 <table>
 <tr align='center'>
  <td>Arduino UNO/NANO</td>
  <td> </td>
 </tr>
 <tr>
  <td>PIN 2</td>
  <td>Relè</td>
 </tr>
 <tr>
  <td>PIN 3 </td>
  <td>Emettitore LED IR</td>
 </tr>
 <tr>
  <td>PIN 4 </td>
  <td>Attuatore</td>
 </tr>
 <tr>
  <td>PIN 8 </td>
  <td>Ricevitore IR</td>
 </tr>
 <tr>
  <td>PIN A4 </td>
  <td>Display SDA</td>
 </tr>
 <tr>
  <td>PIN A5 </td>
  <td>Display SCL</td>
 </tr>
 <tr>
 <tr>
  <td>PIN 10 </td>
  <td>Pulsante Relay</td>
 </tr>
 <tr>
  <td>PIN 11 </td>
  <td>Pulsante Attuatore</td>
 </tr>
 <tr>
 <tr>
  <td>5v </td>
  <td>Breadboard</td>
 </tr>
 <tr>
  <td>GND </td>
  <td>Breadboard</td>
 </tr>
</table>

La differenza, rispetto al primo prototipo, non è solo nello schema fisico, ma anche nella parte di codice per il controllo di ogni singolo nodo.
Infatti gli sketch presentano forti variazioni ripetto agli sketch precedenti.

Ecco lo schema definitivo:

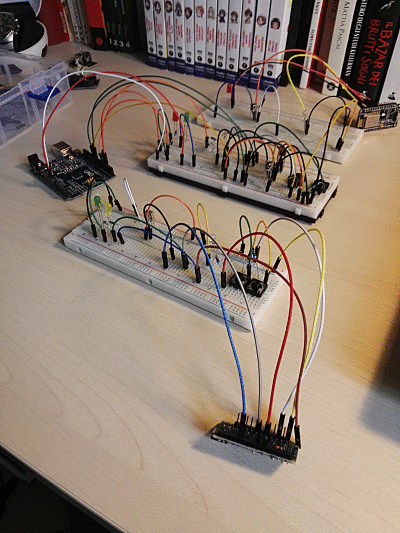
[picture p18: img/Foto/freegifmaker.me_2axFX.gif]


Attraverso questi collegamenti e gli sketch da inserire all'interno di ogni scheda sarà possibile realizzare una comunicazione "Domanda-Risposta" per la comunicazione dei dati.
Infatti:
* Il client invierà la sua richiesta di modifica tramite la pagina HTML;
* Il Nodo Master riceverà il comando decodificando l'URL della pagina ed invierà le azioni da seguire al Nodo 1
* Il Nodo 1 elaborerà il dato inviato:

   * Esegue l'azione se fosse il destinatario(accensione/spegnimento attuatore e/o relè)
     * Restituisce l'ok di avventa lettura al Nodo Master
     * Il Nodo Master riceve l'ACK e aggiorna la pagina
   * Invia dato al Nodo 2 essendo quest'ultimo il destinatario
     * Il Nodo 2 elabora il dato ed esegue le azioni (accensione/spegnimento)
     * Restituisce l'ok di avvenuta ricezione al Nodo 1
     * Il Nodo 1 riceve l'ACK ed invia egli stesso la conferma al Nodo Master
     * Il Nodo Master riceve l'ACK di avvenuta ricezione
     * La pagina si aggiorna

In questo caso la comunicazione tra Nodo 1 - Nodo 2 avviene allo stesso e identico modo della comunicazione tra Nodo Master - Nodo 1:
* Il Nodo 1 manda il dato(continuamente per 8-10 sec.) al Nodo 2 e rimane costantemente in ascolto
* Il Nodo 2, una volta ricevuto il dato, manda continuamente l'ACK di avvenuta comunicazione
* La comunicazione si chiude all'attesa di 10 sec. o con l'invio dell'ACK.
* Se l'ok di comunicazione non avviene questo non giungerà nemmeno al Nodo Master, generando una pagina di errore!

*N.B: Per prevenire l'accavallarsi dei dati, inviati da entrambi i nodi, al Nodo 1 si è pensato di far mandare al Nodo Master il dato un tantum... In questo modo ci saranno dei buchi in cui il Nodo 1 percepirà solo il segnale inviato dal Nodo 2!*

#### *Video*
<table align='center'>
  <tr align='center'>
   <td>Video </td>
   <td>Link</td>
  </tr>
  <tr align='center'>
   <td>Completo</td>
   <td>https://www.youtube.com/watch?v=MiBDAAoGOk4&t=38s</td>
   </tr>
 </table>

_____________________________________
# Database (Firebase)
Adesso non ci resta che implementare un database dove salvare i nostri dati, che saranno visibili in remoto attraverso un'app Android.
Il database che si è utilizzato per questo progetto è [Firebase](https://firebase.google.com/) (database NoSQL).
Firebase è semplice ed intuitivo da utilizzare.
La struttura che utilizza non è una struttura tabellare ma ad albero.

Una volta implementato il DB dobbiamo effettuare la connessione a Firebase grazie ad una librearia per l'ESP8266 che è presente nell'occorrente software elencato a inizio pagina.
Abbiamo bisogno, per il collegamento, dell'HOSTNAME e dell'autorizzazione:
* Accedete allo sketch del Nodo Master attraverso Arduino IDE
* Aprite Firebase
* Andate al vostro DB creato in precedenza
* Copiate l'hostname del DB e incollatelo nello sketch alla variabile FIREBASE_HOST senza https:// e lo / finale
* Andate su Firebase > Impostazioni > Database > Database Secret
* Cliccate su SHOW e copiate il codice di autorizzazione
* Incollate il codice nella variabile FIREBASE_AUTH presente nello sketch

*N.B:Nello sketch postato su GitHub, non è presente ne SSID, Password, FIREBASE_HOST, FIREBASE_AUTH, perchè sono dati sensibili!
Dovrete inserire al posto dei "****" le vostre credenziali.*

Elenchiamo quello che succede nello sketch da eseguire sul Nodo Master(gli altri sketch, delle altre schede poste sugli altri nodi, rimangono invariati):
* Il client accede all'indirizzo IP della pagina HTML e fa una richiesta di modifica dei nodi
* Il Nodo Master riceve questa modifica attraverso la form e manda i dati, attraverso la connessione ottica, al Nodo 1
* Il Nodo 1 elabora i dati e li esegue o li invia al Nodo 2
* Il Nodo 1, una volta eseguito tutto, manda una risposta al Nodo Master, confermando l'avvenuta ricezione
* Il Nodo Master aggiorna la pagina HTML da mandare al client e contemporaneamente aggiorna il DB
* La pagina HTML viene aggiornata

In remoto sarà presente uno smartphone o tablet android con un'app per il controllo dello stato.
Dalla semplice app, realizzata con [AppInventor](http://appinventor.mit.edu/explore/), sarà possibile monitorare lo stato della rete e di tutti i nodi.
In futuro potrebbe essere implementato anche un controllo, in remoto, dell'intera rete.

## *App Android*
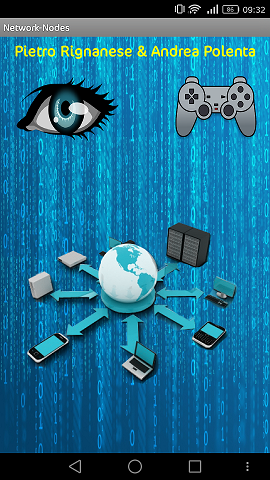
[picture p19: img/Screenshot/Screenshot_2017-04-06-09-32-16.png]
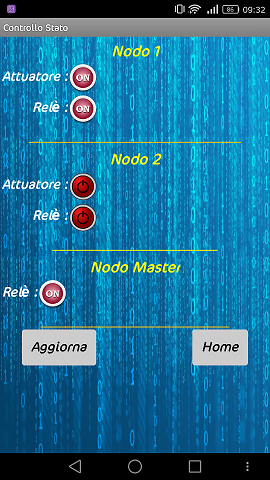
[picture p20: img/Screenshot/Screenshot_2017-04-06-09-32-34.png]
  

Come dicevamo, l'app è stata realizzata attraverso un software open source online della Google: App Inventor.
Tale software è molto semplice ed intuitivo.
in futuro verrà fatta una guida su come utilizzarlo.

L'app presenta una schermata principale in cui ci sono due grossi bottoni:
* Un occhio = rappresenta il controllo dello stato della rete
* Un joypad = rappresenta il controllo in remoto delle modifiche da portare ai nodi

Per il momento il controllo della modifica dei nodi non può essere effettuato (verrà implementato in un secondo momento)
Cliccando sull'occhio abbiamo l'apertura della pagina "Controllo stato", in cui sarà presente lo stato di ogni nodo.
Tale stato sarà prelevato da Firebase.

Potete scaricare il file APK da [QUI](https://github.com/domoticawifi/Network-nodes/blob/master/Android%20APP/NetworkNodes_App_Android.apk) oppure accedere alla cartella "Android APP" sulla pagina principale della reposity di GitHub.
_____________________________________

# Problemi rilevati

In questa parte verranno riportati tutti i problemi rilevati durante la realizzazione del progetto; questi problemi sono già riportati nella relazione, questa sezione è solo un resoconto di tutti i problemi e le loro risoluzioni.

## *Problemi*
* Alimentazione instabile shield ESP8266
* Lettura instabile sensore IR Nodo Master
* Interruzione comunicazione ottica da parte di un oggetto o altro
* Comunicazione "Connected Oriented" Nodo 1 - Nodo 2

## *Soluzioni*
* L'alimentazione instabile (5v) della shield, non ci ha permesso di collegare il sensore IR con i 5v della scheda; si è risolto tale problema alimentando il sensore con i 5v di un'altra scheda Arduino.
* La lettura instabile del sensore IR sul Nodo Master non è stato risolto! Purtroppo la scheda rileva letture random di valori non conformi a quelli inviati dal nodo adiacente. Questo problema è dato solo dal Nodo Master, mentre la comunicazione tra il Nodo 1 e Nodo 2 avviene in modo impeccabile. Questo problema è comunque in parte risolto grazie all'invio continuo dell'ACK da parte del Nodo 1 al Nodo Master, in modo da fargli leggere, prima o poi, l'ok di avvenuta ricezione. Purtroppo la sicuezza assoluta non c'è!
* L'interruzione della comunicazione può avvenire in due modi: 
   * Oggetto che ostacola la comunicazione ottica;
   * Malfunzionamento di uno dei componenti di comunicazione.
   
  Per entrambi i casi si è previsto un javascript con un WARNING.
  
* Per la comunicazione "Connected Oriented" tra Nodo 1 e Nodo 2 si è pensato a una serie di soluzioni che potrebbero risolvere il problema:
  * <a href="#ancora-protdue-sol2">Sensore sferico</a> 
  * Triangolazione del segnale 
  * Serie di specchi per dirigere il segnale 
  * Schema di switch per doppio sensore 

_____________________________________

# Algoritmi
### *Nodo Master:*

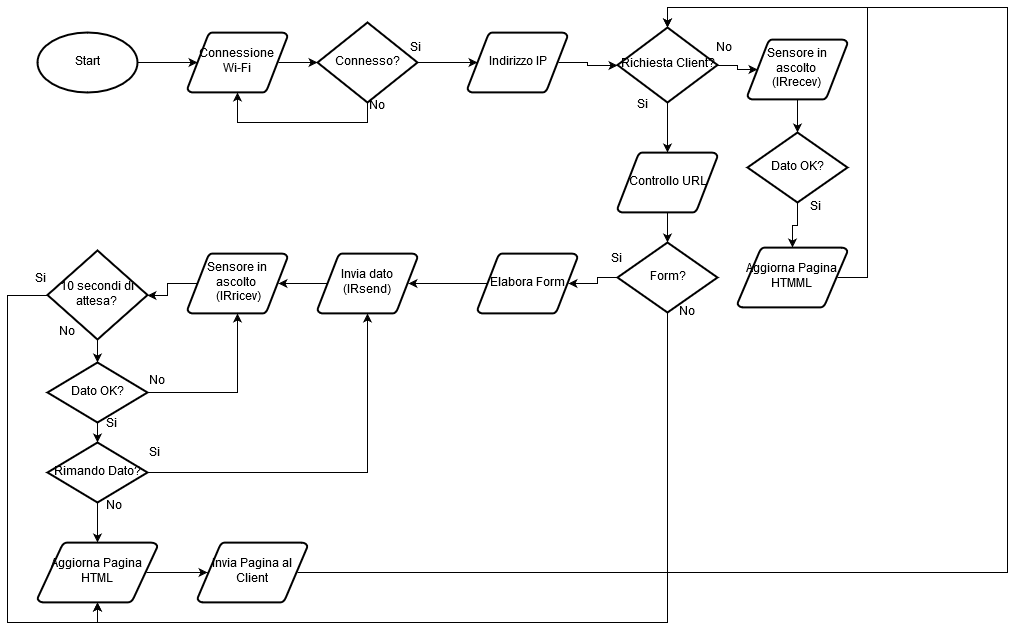
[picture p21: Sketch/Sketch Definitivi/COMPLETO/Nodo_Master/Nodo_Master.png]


### *Nodo 1:*

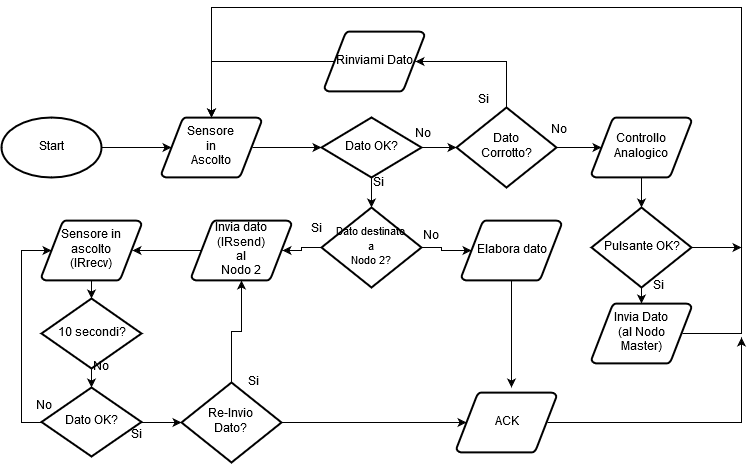
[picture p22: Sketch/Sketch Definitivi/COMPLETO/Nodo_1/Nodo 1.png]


### *Nodo 2:*
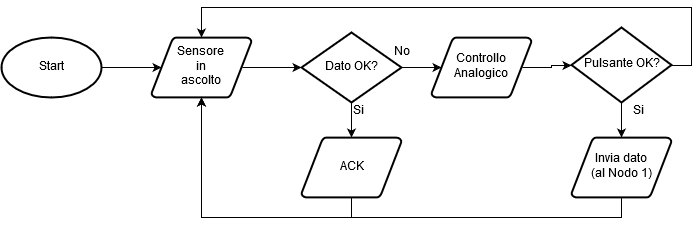
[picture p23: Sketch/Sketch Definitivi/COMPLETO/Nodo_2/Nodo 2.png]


______________________________________

# Conclusioni e costi complessivi

### *Costi:*
I costi dei vari moduli, schede, cavi, breadboard, led e altro si aggira intorno a questo range: 30€ - 70€.
il tutto dipende da dove compriate il materiale.
Il consiglio che vi diamo è quello di comprare tutto su e-Bay... è un sito molto sicuro e trovate tutto quello di cui avete bisogno.
Vi allego il link del venditore dove abbiamo reperito tutto il materiale:
http://www.ebay.it/usr/nouteclab?_trksid=p2047675.l2559

### *Conclusioni:*
Riportiamo le conclusioni con un elenco puntato:
* Miglioramento capacità tecniche e pratiche in:

  * Informatica
  * Programmazione
  * Elettronica
  * Comunicazioni
  
* Miglioramento rapporti di coesione e lavoro di squadra
* Rendere più performante la comunicazione ottica sostituendola con quella a onde radio
  
  * Utilizzando le onde radio si migliora la qualità del segnale inviato
  * La comunicazione può avvenire in modo diretto tra Nodo Master e Nodo 2
  * Si instaurerà un ponte di nodi, per la comunicazione, solamente se i nodi si trovassero fuori dal range di comunicazione
  * Se dovesse presentarsi un ostacolo permanente o no, il segnale passerebbe ugualmente
  
 ### Tempi di comunicazione:
 
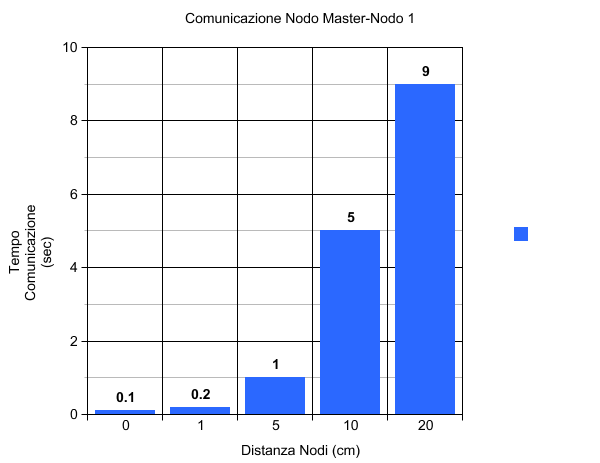
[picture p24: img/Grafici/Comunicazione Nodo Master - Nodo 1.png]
 
 
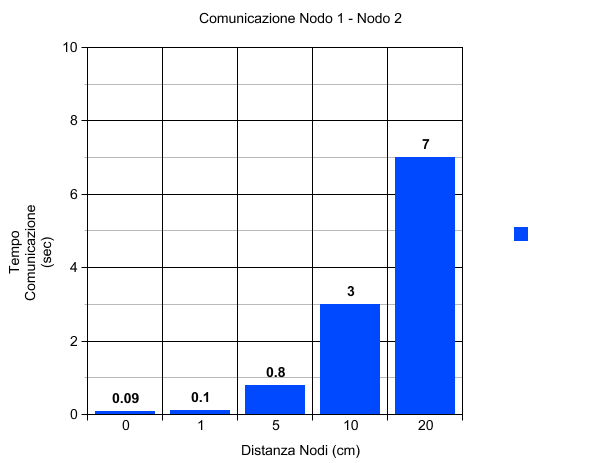
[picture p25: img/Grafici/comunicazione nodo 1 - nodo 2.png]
 

 __________________________________________________________________
 
 ## <a href="#ancora-indice">Torna all'indice </a>
 
      

 ### Network-Nodes: Pietro Rignanese & Andrea Polenta Aprile 2017
 


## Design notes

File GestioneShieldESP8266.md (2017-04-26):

# Gesione 

## Cos'è l'ESP8266?
L'ESP8266 è una scheda che incorpora l'uso del Wi-Fi.
Si hanno tanti tipi di ESP8266, cambiano forme e costi, ma essenzialmente svolgono lo stesso principio.
Per questo progetto si è utilizzato un ESP8266 ESP-12E con scheda di programmazione già integrata, per facilitarne l'utilizzo.

La scheda presenta 30 pin e un'alimentazione attraverso micro USB.
Questo tipo di scheda può sostituire o essere un degno alleato di arduino, perchè dispone di pin che possono essere utilizzati per la gestione di dati di INPUT e/o OUTPUT.
La scheda, come si può vedere, è compatta, leggera, di buona fattura e può essere utilizzata per vasti utilizzi (domotica, robotica, automazione in generale).

## Come installare la scheda su Arduino
* Lancia l'IDE di Arduino dal tuo PC
* Vai su *File* > *Impostazioni*
* Inserisci questo link `http://arduino.esp8266.com/stable/package_esp8266com_index.json` nelle URL aggiuntive per la gestione delle schede e clicca su OK

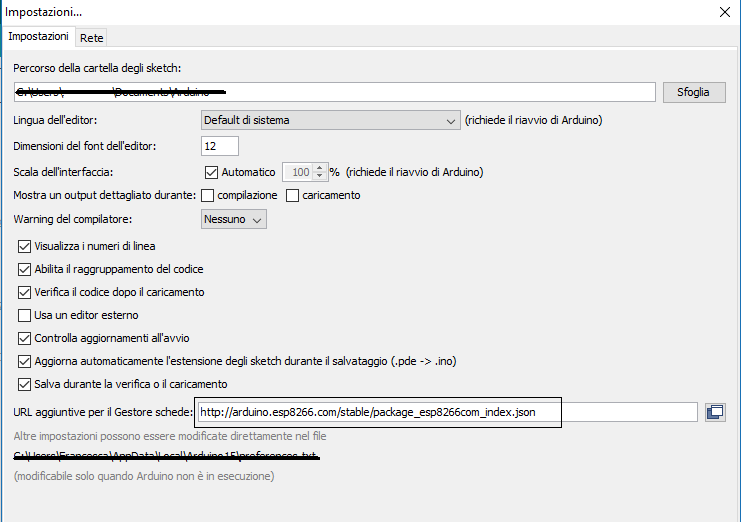
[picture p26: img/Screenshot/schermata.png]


* Vai su *Strumenti* > *Gestione Schede* e installa la piattaforma "ESP8266"

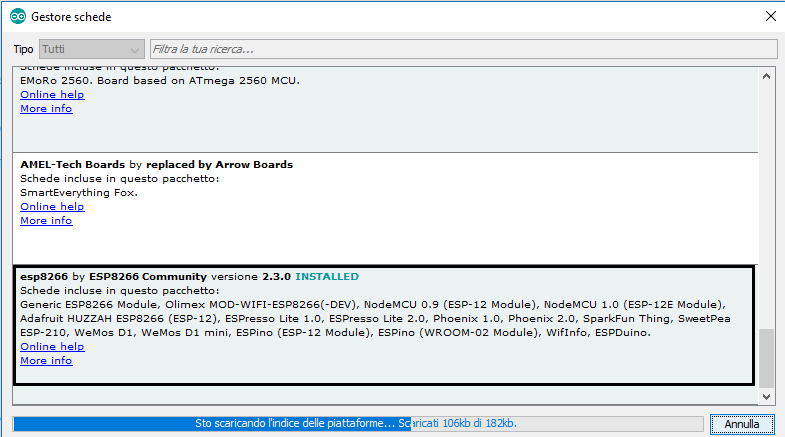
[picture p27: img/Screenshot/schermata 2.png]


* Installare la [libreria ESP8266](https://github.com/googlesamples/firebase-arduino/archive/master.zip) aggiuntiva della scheda

*N.B: Installazione di questo pacchetto aggiuntivo per l'IDE di Arduino, comprende tante schede WI-FI in commercio*

## Come utilizzare la scheda ESP8266
* Lancia Arduino
* Selezione *Strumenti* > *Schede* e seleziona la shcheda che vuoi utilizzare nella sezione "ESP8266 Modules"

Noi utilizziamo, per questo progetto, una ESP8266 ESP-12E, quindi selezioneremo la scheda ESP-12E MODE MCU 1.0.

## Come collegare la scheda ESP8266 alla rete WI-FI  
Per collegare la shield Wi-Fi, ad un router, dobbiamo seguire questi passi:
* Collegare la shield, tramite cavo mini USB, al PC
* Aprire l'IDE di Arduino 1.8.0 o superiori
* Andare su *Strumenti* e selezionale la scheda ESP8266 corrispondente a quella inserita(nel nostro caso MODE MCU 1.0)
* Impostare la porta di collegamento seriale (Esempio COM4)
* Impostare il bound rate a 115200
* Lanciare il [programma](https://github.com/domoticawifi/Network-nodes/blob/master/Sketch/Sketch%20Di%20Prova/sketch_Connessione_Rete_WiFi.ino) per la connessione

## Programma di lancio per il collegamento
Analizziamo, riga per riga, il programma di lancio per il collegamento della scheda al router.

*N.B: abbiamo utilizzato, per le varie prove, un hotspot Wi-Fi con un HUAWEI P8. Il telefono, in questo caso, funge da router...*

Codice:
* Includiamo la libreria che abbiamo scaricato in precedenza, per utilizzare, più facilmente, le funzionalità della shield Wi-Fi (#include ESP8266.h)
* Creiamo due variabili di tipo string ed andiamo ad inserire le credenziali per l'accesso al router SSID e Password
* SSID è il nome della rete, nel nostro caso HUAWEI P8
* La Password è quella con cui accedete al router, per connettervi a internet
* Impostiamo la porta 80 per la comunicazione
* Nel ciclo di loop è presente la parte di programma che andrà a connettere la shield al router
* Una volta avvenuta la connessione verrà visualizzato, sulla porta seriale di arduino, l'indirizzo IP della scheda
* La scheda risulterà collegata alla rete LAN

*N.B: Potete verificare l'indirizzo IP, di ogni dispositivo connesso, andando sull'indirizzo IP del router, accedendo tramite browser. Di solito i router hanno come indirizzo 192.168.0.1. Potete verificare il vostro indirizzo di router sul manuale di quest'ultimo*

__________________________________________________



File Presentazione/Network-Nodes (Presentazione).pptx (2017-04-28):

## Network-Nodes

Pietro Rignanese & Andrea Polenta

## Realizzazione di una rete LAN(a nodi) con comunicazione ottica.

Rete a nodi
Occorrente Hardware:
- Terminale (PC, Smartphone, tablet, etc…)
- Router Wi-Fi
- Nodo Master (Shield Wi-Fi ESP8266)
- Nodo 1 (Arduino UNO/NANO)
- Nodo 2 (Arduino UNO/NANO)

## Realizzazione di una rete LAN(a nodi) con comunicazione ottica.

Rete a nodi
Occorrente Software:
- Arduino IDE 1.8.0 o superiori
- Firebase
- Core ESP8266
- Libreria gestione ESP8266
- Libreria gestione segnale IR
- Libreria gestione Display LCD

## Cos’è una rete LAN?

Una Local Area Network (LAN) è una rete informatica di collegamento tra più dispositivi(computer, portatili, smartphone…) che copre un'area limitata, come un'abitazione, una scuola, un'azienda. Si tratta storicamente delle prime tipologie di reti informatiche realizzate al mondo per semplicità di realizzazione e costi sostenibili anche da piccoli privati. Le tecnologie utilizzate, per la comunicazione, sono Ethernet e il Wi-Fi.

## Qual è il nostro scopo?

Il nostro scopo è quello di creare una piccola rete LAN, formata da 3 nodi (Nodo Master, Nodo 1 e Nodo 2) per la comunicazione di informazioni e il cambiamento di stato di eventuali attuatori, e/o relè posti nella rete. Lo scopo principale è quello di centralizzare il controllo di dispositivi automatici e/o semi-automatici, monitorando il tutto da un semplice device.

## Costi di progettazione

- Shield Wi-Fi ESP8266 : 5€ – 10€
- Breadboard : 3€ - 10€
- Cavetti per collegamenti e jumper : 3€ - 6€
- Sensori Infrarossi (Almeno 4) : 1€ - 2€ (Singolo pezzo)
- Emettitori LED Infrarossi (Almeno 3) : 0.80€ - 2€ (Singolo pezzo)
- Arduino UNO : 20€
- Arduino UNO (Compatibile) : 8€
- Arduino NANO : 10€
- Arduino NANO (Compatibile) : 4€
- LED per simulare attuatori e/o relè(Almeno 5) : 0.20€ - 1€ (Singolo pezzo)
Costo totale: 30,50€ - 75€

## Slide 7

Ecco uno schema grafico di ciò che andremo a realizzare

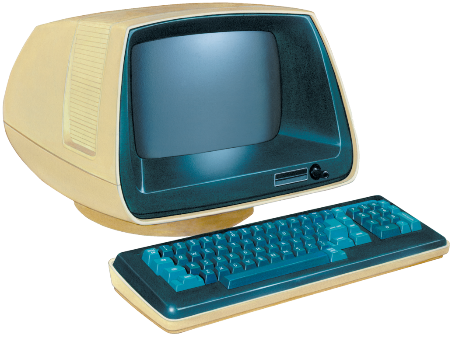
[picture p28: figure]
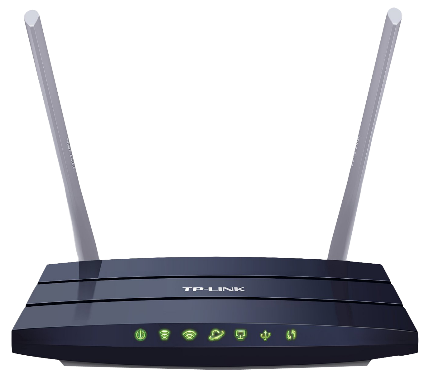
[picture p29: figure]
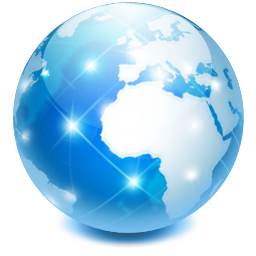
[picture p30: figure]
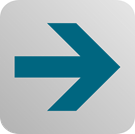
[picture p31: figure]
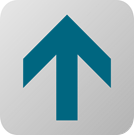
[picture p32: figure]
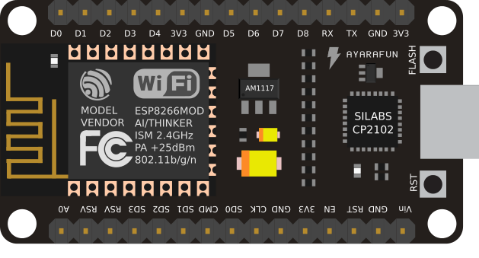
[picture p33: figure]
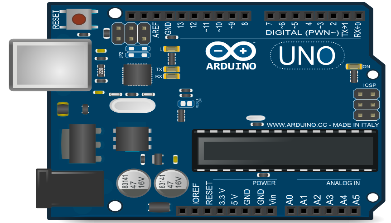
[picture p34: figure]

## Struttura

Da come si può notare dallo schema precedente, abbiamo previsto un terminale PC, un nodo ‘master’ e due nodi ‘slave’ , schematizzati nella seguente maniera (classifichiamo questa rete come P2P):
- Terminale (Invia e riceve le informazioni di tutta la rete)
- Router (Instrada le richieste fatte tra terminale e nodo master sulla rete domestica e anche quella esterna andando ad aggiornare un DB)
- Nodo Master (Nodo formato da un modulo ESP8266 ESP-12E per il collegamento WI-FI con il terminale, l'invio delle informazioni sul DB e la trasmissione di informazioni tra i vari nodi presenti nella rete locale.
- Nodo1 (Nodo formato da Arduino NANO che gestisce un attuatore/relè/led e, in futuro, un eventuale sensore
- Nodo2 (Stessa cosa del nodo precedente)
N.B: Lo storage delle informazioni su un DB, ci serve per cotrollare lo stato della rete, anche da smartphone o tablet, in remoto (Internetworking: il router fungerà da gateway). Il Nodo Master può essere provvisto di attuatori e sensori.

## Comunicazioni

Le comunicazioni fra i vari nodi ed il terminale avvengono nella seguente maniera:
- Il terminale comunica con il solo Nodo Master tramite la rete WI-FI, ricevendo ed inviando a questo nodo le richieste per gli altri due nodi della rete e le risposte provenienti da questi ultimi.
- Il Nodo Master comunica con il terminale via WI-FI e con il Nodo1 attraverso un collegamento ottico (LED IR e Sensor IR), quest’ultima è anche la comunicazione che sussiste tra il Nodo1 e Nodo2
- Ogni nodo può comunicare solamente con il suo nodo adiacente formando un ponte di nodi
- Se il terminale deve contattare il Nodo2, la sua richiesta passerà prima al nodo ‘master’ poi al Nodo1 arrivando infine a destinazione nel Nodo desiderato.

## Nodo ‘Master’

Il Nodo ‘Master’ è il nodo che, di fatto, nel nostro sistema, comanda gli altri nodi e invia loro le giuste informazioni per attivare i loro terminali.
Dispone anch’ esso di un terminale, che noi abbiamo pensato essere un semplicissimo LED.
Il ‘Master’ è tale grazie alla scheda Wi-Fi ESP8266 12-E poiché grazie a quest’ultima riesce ad ottenere le giuste informazioni da terminale PC e quindi di poterle smistare come da richiesta.
Riportiamo in seguito la rappresentazione grafica dei collegamenti effettuati al fine di rendere operativo tale Nodo:


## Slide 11

- Nodo1

Questo è il nodo immediatamente successivo al Nodo ‘Master’ in termini di passaggio delle informazioni, fondamentalmente non è altro che un ‘Master’ per il Nodo2 che invece è uno ‘Slave’ in ogni caso; è capace di elaborare le informazioni che giungono ad esso, comprendendo se devono essere utilizzate per l’attivazione/disattivazione dei terminali locali oppure se il loro compito è quello di attivare/disattivare i terminali del Nodo2. In quest’ultimo caso il Nodo1 invierà tramite l’apposito Trasmettitore IR tutti i dati utili per tale funzione al Nodo2.
Presenta un Arduino UNO adibito al suo controllo, 2 LED, 1 Trasmettitore IR, 1 Emettitore IR.

- Nodo2

Come detto, il Nodo2 è uno ‘Slave’ a tutti gli effetti, di fatto elabora le informazioni in arrivo dal Nodo1 e le adopera solo ed esclusivamente per attivare/disattivare i terminali locali ad esso.
Presenta un Arduino UNO adibito al suo controllo, 2 LED, 1 Trasmettitore IR, 1 Emettitore IR.

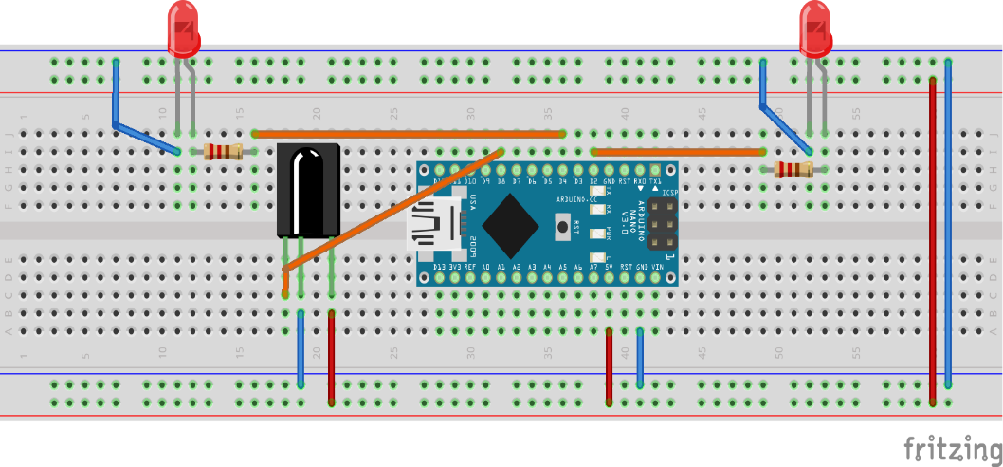
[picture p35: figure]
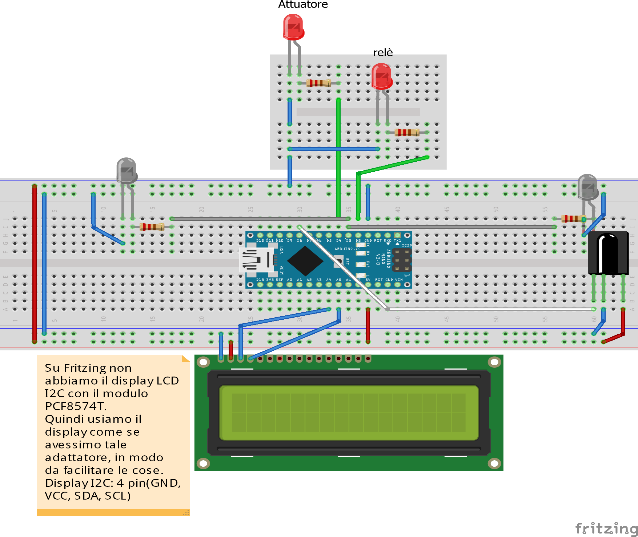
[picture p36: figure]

## Nodo Master:


## Esempio comunicazione PC >> Nodo ‘Master’ >> Nodo 1

Richiesta Wi-Fi effettuata dal PC nei confronti del Nodo ‘Master’
Nel Nodo Master andremo a caricare una pagina HTML dalla quale sarà possibile effettuare una richiesta al Nodo ‘Master’. Tale richiesta può essere effettuata attraverso tutti i device collegati con la rete Wi-Fi nella quale risulta connessa l’ESP8266.
Richiesta Wi-Fi ricevuta dal Nodo ‘Master’
Elaborazione dei dati ottenuti al fine di comprendere se questi servono per operazioni locali alla scheda ESP8266 oppure se necessitano di essere inoltrati attraverso il trasmettitore IR al Nodo adiacente.
Richiesta Infrarossi effettuata dal Nodo ‘Master’ nei confronti del Nodo1
Dopo l’elaborazione, se l’intenzione iniziale era quella di inviare informazioni al Nodo1, allora i risultati suggeriranno al Nodo ‘Master’ di inoltrare i dati al Nodo1 attraverso il trasmettitore IR. Dopodiché il ‘Master’ si mette in ascolto per 10 secondi.
Richiesta infrarossi ricevuta dal ricevitore IR del Nodo1
Elaborazione dei dati ottenuti al fine di comprendere se questi sono validi o meno.
Se sono validi il Nodo1 attraverso il trasmettitore IR invia un’ACK al ‘Master’ altrimenti il dato viene dichiarato corrotto oppure se non ritorna affatto la connessione viene decretata scaduta.
Operazione locale
Se i dati sono validi, dopo l’invio dell’ACK, il ‘Master’ chiude la connessione ed aggiorna la pagina HTML, mentre, il Nodo1, provvede ad attivare/disattivare i terminali locali o inoltrate i dati al Nodo2.

## 1) Connessione scheda Wi-Fi con una rete LAN

WiFiServer server(80);
Creiamo un’istanza del server
const char* ssid = “SSID"; const char* password = “PASS";
Specifichiamo le credenziali della rete alla quale vogliamo connetterci
WiFi.begin(ssid, password);
Inizializzazione della connessione Wi-Fi
WiFi.status() != WL_CONNECTED
WiFiClient cliente = server.available();
WL_CONNECTED rimane è un valore di tipo boolean che rimane a false finché la connessione non è avvenuta;
Controllo di avvenuta connessione Client/Server-

#include <ESP8266WiFi.h>

Includiamo l’apposita libreria nello Sketch al fine di poter definire una connessione

## Nodo 1:


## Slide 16

Inoltro dati ad uno dei nodi tramite Trasmettitore IR

irsend.begin(); irrecv.enableIRIn();
Inizializzazione della trasmissione e della ricezione infrarossi
irsend.sendNEC(0x0000000001, 32)
Invio del dato di accensione/spegnimento
irrecv.decode(&results);
results.value;
Al momento della ricezioni, tali variabili conterranno i valori ricevuti;
irrecv.resume();
Al Funzione che da la possibilità al sensore di mettersi in ascolto sul dato successivo, pulendo la sezione di memoria adibita a contenere di dati ricevuti

#include <IRremoteESP8266.h>

Includiamo l’apposita libreria nello Sketch al fine di poter determinare delle connessioni infrarossi

IRsend irsend(D0);

Creiamo l’oggetto adibito alla trasmissione dell’informazione al pin D0

IRrecv irrecv(D3);

Creiamo l’oggetto adibito alla ricezione dell’informazione al pin D3

## Nodo 2:


## Aggiornamento DB

Nodo 1
Riceve dato
Manda risposta
Nodo Master
Riceve ACK
Inoltra pagina HTML
Firebase
Riceve modifiche
Aggiorna DB
Manda modifiche al DB

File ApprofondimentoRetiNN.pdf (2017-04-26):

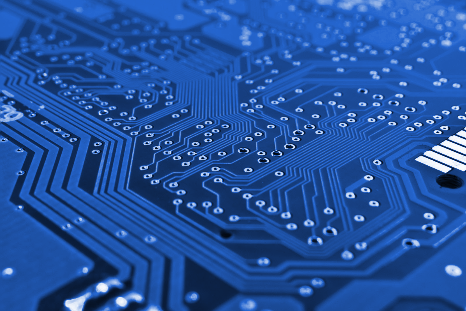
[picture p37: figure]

# Progetto Network-Nodes

Approfondimento riguardante le connessioni adoperate nel progetto Calcolatori elettronici e reti di calcolatori

### Pietro Rignanese & Andrea Polenta Università politecnica delle Marche

## INDICE

## - Pagina 2 | Reti WLAN

- Pagina 3,4,5 | Reti P2P
- Pagina 5 | Reti BSS
- Pagina 6 | Reti ESS

## - Pagina 7 | Applicazioni

## - Pagina 8 | Standard IEEE802.11

- Pagina 9 | Gli standard della famiglia IEEE 802.x

## - Pagina 10 | Reti PAN

- Pagina 11 | ZigBee

## - Pagina 11 | Reti BAN

## - Pagina 12 | Reti IR

- Pagina 13 | L’IrDA
- Pagina 14,15 | Protocolli IrDA

## Overview

Ciò che vogliamo riportare nelle pagine seguenti sono degli approfondimenti legati alle connessioni effettuate tra i vari dispositivi durante lo svolgimento del progetto. Le connessioni adoperate sono la connessione di tipo Wireless e di tipo Ottico ad infrarossi(IR).

## Breve resoconto del progetto

Al fine di rendere più chiare la natura delle connessioni ricordiamo brevemente la struttura del nostro progetto.
Il nostro sistema di nodi prevede di fatto un Device di vario tipo (PC, Smartphone, Tablet) che sia in grado di effettuare una connessione ad una rete di tipologia WLAN, un nodo Master, anch'esso capace di stabilire una connessione WLAN attraverso l’ESP8266 12-E, un primo nodo Slave per il nodo Master e un secondo nodo Slave per il primo entrambi capaci di comunicare tra di loro attraverso delle connessioni infrarossi ottenute da trasmettitori e dei ricevitori IR.

## Reti WLAN

Come espresso in precedenza, sia il Device che passa informazioni al Master, che lo stesso nodo Master, devono essere capaci di interfacciarsi ad una rete WLAN: una rete WLAN (Wireless Local Area Network) è una particolare rete locale che invece di sfruttare una connessione via cavo per connettere fra di loro gli Host della rete, sfrutta la connessione Wireless, cioè senza fili. Possiamo rilevare tre differenti tipologie di installazioni di tali reti WLAN:
❏ P2P o Ad-Hoc
❏ Infrastructure Basic Service Set
❏ Extended Service Set

P2P o Ad-Hoc
Vengono anche dette reti paritarie | o paritetiche, ciò perché di fatto sono
modellate su di un’architettura logica in cui i nodi | (gli Host | nel caso delle reti WLAN)
non sono gerarchizzati, cioè il loro ruolo non è definito a priori tra quello di Client o quello di Server, tali ruoli risultano mixati tra di loro in maniera tale che un nodo può fungere sia da client che da server.

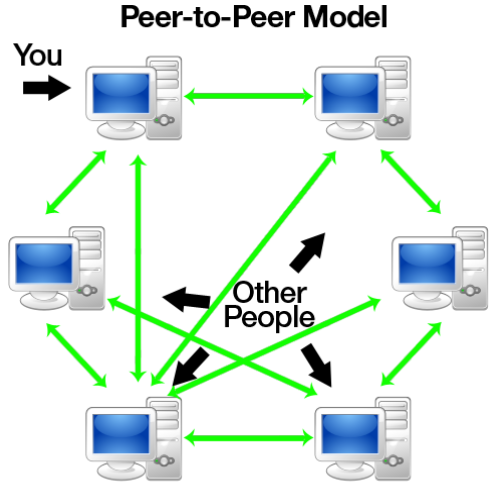
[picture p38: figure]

Un esempio pratico di tale tipologia di rete, anche se non realizzata in modalità Wireless, lo possiamo notare anche nel nostro progetto; il nodo 1 risulterà essere sia Master che slave all’interno del contesto considerato.
Mediante questa configurazione qualsiasi nodo è in grado di avviare o completare una transazione. I nodi equivalenti possono differire nella configurazione locale, nella velocità di elaborazione, nella ampiezza di banda e nella quantità di dati memorizzati.
Ovviamente questa tipologia di rete ha dei vantaggi e degli svantaggi, conoscerli sarà fondamentale per comprendere se quest’ultima è quella giusta per il sistema che vogliamo creare:
- Non si deve acquistare un server con potenzialità elevate e quindi non se ne deve sostenere il costo, tuttavia ogni computer dovrà avere i requisiti per sostenere l'utente in locale, in rete e anche tutti gli altri utenti che desiderano accedere alle risorse di questo in remoto;
- Ogni utente condivide localmente le proprie risorse ed è amministratore del proprio client-server. Questo da un lato può essere positivo per una questione di "indipendenza", ma dall'altro richiede delle competenze ad ogni utente, soprattutto per quel che concerne la protezione;
- La velocità media di trasmissione dei dati è molto più elevata di una classica rete con sistema Server / Client, dal momento che l'informazione richiesta da un Client può essere reperita da numerosi Client connessi in modo paritario (ossia "peer"), anziché da un unico server (questo tipo di condivisione diventa tanto più efficace tanti più sono i Client connessi, in antitesi con la rete tradizionale Server/Client, dove un elevato numero di Client connessi riduce la velocità di trasmissione dati per utente);
- La sicurezza degli accessi ai client viene gestita localmente su ogni macchina e non centralizzata, questo significa che una rete basata su utenti deve avere lo stesso archivio reimpostato in ogni client;
Queste tipologie di reti esulano dalla tipologia di connessione, di fatto Peer-to-Peer identifica un modello di interconnessione fra vari soggetti che non debbono rispettare gli schemi rigidi del Client/Server ma possono mutare la loro natura in base alle necessità. Ad esempio il termine P2P viene spesso adoperato per identificare le reti di file Sharing. Reti come quelle in cui si interfacciano software
come Utorrent e Vuze | (Azureus) | sono reti FileSharing-P2P | e vengono adoperate
per la diffusione di grandi file ad alta velocità.
I suddetti software sono completamente compatibili con BitTorrent che è uno dei più popolari protocolli P2P. I vantaggi di queste tipologie di protocolli nell’ambito del file sharing sono dovuti al fatto che i vari nodi presenti nel sistema contribuiscono alla diffusione dei file, questo metodo riduce l’impatto della “leech resistance”.

Le principali funzionalità dei software P2P sono:
- supporto multipiattaforma, multiserver, multicanale: il programma è compatibile con tutti i sistemi operativi, server e dispositivi hardware (PC, laptop portatili, palmari, cellulari);
- supporto protocollo IPv6;
- download dello stesso file da più reti contemporaneamente;
- offuscamento dell'ID di rete;
- offuscamento del protocollo P2P;
- supporto proxy e Tor;
- supporto crittografia SSL;
- gestione da remoto, sia da PC/notebook che da cellulari e palmari.

Infrastructure Basic Service Set
Nella modalità infrastruttura ogni computer stazione (sigla STA) si connette ad un Access Point con un collegamento senza fili. L'insieme formato dal punto di accesso e dalle stazioni poste nella sua zona di copertura è detto insieme di servizi di base (BSS) e costituisce una cella. Ogni BSS è identificato da un BSSID, un identificativo di 6 byte che corrisponde all'indirizzo MAC del punto di accesso.

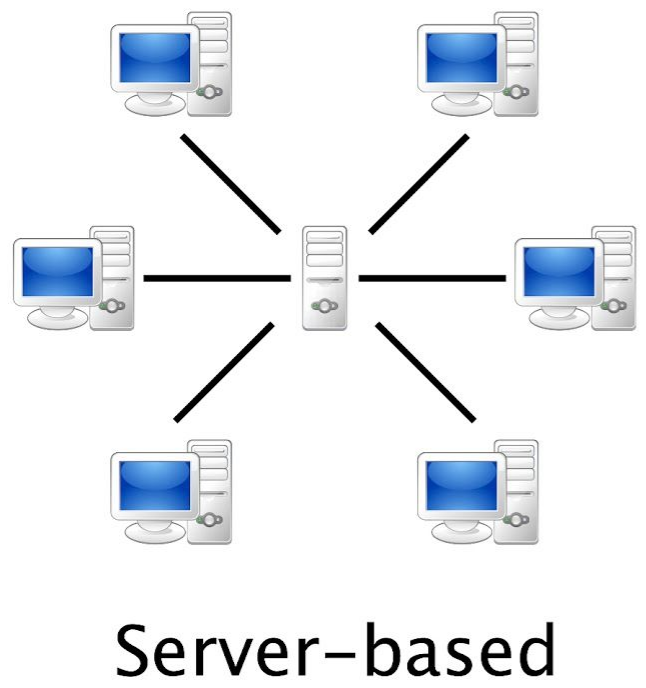
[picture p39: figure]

L’architettura dell’Infrastruttura BSS è di tipo cellulare
- Il sistema è diviso in celle costituite dalle BSS;
- Ciascuna cella è controllata dall’AP;
- La comunicazione tra stazioni avviene solo attraverso l’AP;

Extended Service Set
Una WLAN ESS si basa sul collegamento di due o più WLAN BSS tra loro al fine di generare un'area di maggiore copertura. Grazie alla funzione del roaming, prevista dallo standard IEEE 802.11, un utente della WLAN ESS può passare da una cella (BSA) all'altra senza risentire di alcuna interruzione del servizio e quindi in modo totalmente trasparente. È importante che le celle wireless in configurazione ESS si sovrappongono almeno del 10% per garantire questa funzionalità.

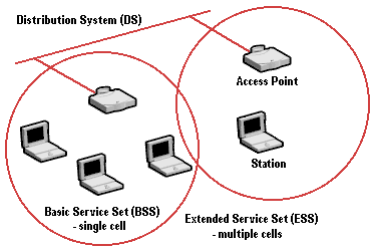
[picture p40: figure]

Il Distribution System è uno strato residente in ciascun AP che funge da dorsale della WLAN, attraverso il quale un AP comunica con un altro AP per:
- Scambiare pacchetti destinati alle stazioni nei rispettivi BSS
- Girare pacchetti per inseguire le stazioni mobili che si spostano da un BSS ad un altro
- Scambiare pacchetti con una rete su cavo
Lo standard 802.11 lascia libertà di scelta (in ambito IEEE 802 LAN) della tecnologia utilizzabile per l’implementazione del DS, e stabilisce i servizi che esso deve fornire
- Il DS si può basare sia su una LAN 802.3 su cavo, che su una rete wireless 802.11
- 802.11f standardizza il protocollo Inter-Access Point Protocol(IAPP)
- Registrazione degli AP in una rete
- Scambio di informazioni tra AP quando una stazione si muove tra aree di copertura supportate da AP di diversi produttori

### Applicazioni

Le reti WLAN sono alla base delle reti domestiche e aziendali. Risultano molto vantaggiose in edifici molto vecchi nei quali non vi è la possibilità o risulterebbe molto costoso e complicato operare modifiche per creare un adeguato sistema di cablaggio strutturato. Inoltre risultano vantaggiose anche nel caso in cui si necessiti di una rete temporanea, ad esempio nel caso di fiere o manifestazioni che durano solo alcune settimane o mesi, di fatto creare un sistema cablato sarebbe molto complesso e dispendioso anche in termini di lunghezza dei cavi, dunque risultano fondamentali queste tipologie di reti.

### Standard IEEE 802.11

L’IEEE 802.11 è un insieme di standard di trasmissione per le reti WLAN. Tutti quegli apparati radio che adottano tale standard vengono identificati con il logo in figura il quale indica l’appartenenza di tale dispositivo alla Wi-Fi Alliance. Tale standard fa parte dell’IEEE 802
LAN/MAN Standards Committee (LMSC) commissione dell'IEEE preposta a sviluppare standard per le reti locali (LAN) e per le reti metropolitane (MAN). Più

precisamente, gli standard "802" sono dedicati alle reti che hanno pacchetti di lunghezza variabile.
I protocolli ed i servizi specificati negli standard 802, quindi anche l’802.11, si situano nei due livelli più bassi (fisico e Data Link) nel modello di riferimento a sette strati espresso dallo standard ISO-OSI. I protocolli 802 suddividono lo strato OSI DLL in due sottostrati, chiamati Logical link control (LLC) e Media Access Control (MAC), in modo tale che gli strati 802 possono essere indicati in questo modo:
- Data link layer
- Sottostrato LLC
- Sottostrato MAC
- Strato fisico (Phy)
Similmente ad Ethernet IEEE 802.3, lo standard IEEE 802.11 definisce
- Le funzioni necessarie ad una stazione 802.11 per operare sia in modalità peer-to-peer che integrata con una LAN esistente
- La privacy e la sicurezza dei dati dell’utente trasportati sul mezzo radio
- Il sottostrato MAC per l’accesso al mezzo
- Lo strato fisico (PHY) e le relative interfacce
La famiglia 802.11 prevede quattro protocolli dedicati alla trasmissione delle
informazioni | che sono i protocolli a, b, g, n; poi troviamo presente il protocollo
per la sicurezza | che però è stato incluso in uno standard a parte, l’802.11i. Poi
abbiamo i protocolli per la famiglia | che sono i seguenti: c, d, e, f, h | ed altri ancora
che però hanno una minore rilevanza, questi riguardano miglioramenti dei servizi già disponibili e estensioni per i servizi di base.
Due dei protocolli più diffusi sono gli 802.11b | e 802.11g | che utilizzano lo spettro di
frequenze dei 2,4 GHz | per il trasferimento delle informazioni; si tratta di una banda
di frequenze assegnata dal piano di ripartizione nazionale ed internazionale ad altro servizio e lasciato di libero impiego solo per le applicazioni che prevedono
livelli di EIRP (https://it.wikipedia.org/wiki/EIRP) | (Equivalent Isotropic Radiated Power, ovvero la massima potenza
irradiata da un'antenna isotropa) di non superiori a 20 | dBm (https://it.wikipedia.org/wiki/Decibel#Decibel_assoluti) | e utilizzate all'interno
di una proprietà privata (no attraversamento suolo pubblico). Le problematiche sorte relativamente ai dispositivi governati da tali protocolli erano dovute al fatto che questi lavorano sulle stesse frequenze di altri dispositivi largamente adoperati nelle abitazioni, come cordless, ripetitori audio/video etc. L’802.11a utilizza invece la banda dei 5.4GHz ma non dispone di alcune importanti funzionalità previste dall’ETSI EN 301 893. Per ovviare al problema in Europa è stato introdotto nel 2004 il protocollo 802.11h, che risponde ai requisiti richiesti. Un apparato WiFi per trasmettere su suolo pubblico in Italia a 5.4 GHz deve quindi utilizzare questo standard.

### Gli standard della famiglia IEEE 802.x

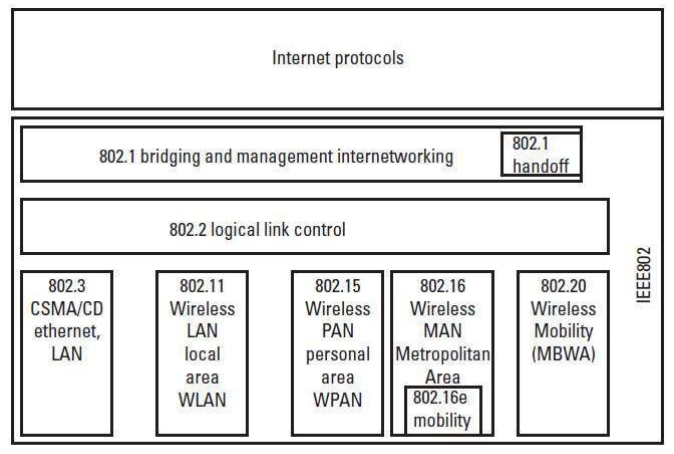
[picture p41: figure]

### Le Reti PAN

Le reti PAN | si pongono nell’insieme delle reti che vengono identificare in base al
loro raggio di copertura quindi insieme alla LAN, MAN | e WAN. Il termine PAN sta
per Personal Area Network | e quindi identifica tutte
quelle reti che hanno come nodi dei device appunto ‘personali’ cioè spazialmente vicini all’utente che li adopera (Smartphone, PC Tascabili, Tablet…) . Entriamo in contatto con questi oggetti quotidianamente generando di conseguenza delle reti PAN.
Le PAN | Bluetooth (https://it.wikipedia.org/wiki/Bluetooth) | sono chiamate anche piconet | e
queste sono composte al massimo da otto dispositivi

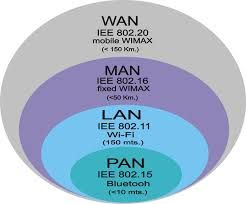
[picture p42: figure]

in relazione master-slave. Il primo dispositivo Bluetooth è il master mentre i successivi diventano slave. Una rete piconet ha un raggio tipico di 10 metri ma si possono collegare più piconet utilizzando un dispositivo che appartenendo a entrambi le piconet fa da ponte, in questo caso la rete che si viene a creare è chiamata scatternet.
La wireless personal area network (WPAN) è una PAN che utilizza come mezzo trasmissivo le onde radio invece degli usuali cavi. La rete Bluetooth forma una WPAN e questa tipologia di rete è definita nell'IEEE 802.15. Un altro tipo di rete WPAN è ZigBee.
ZigBee
ZigBee è uno dei più importanti standard di comunicazione curato dalla ZigBee Alliance; essendo di fatto una rete WPAN, si basa sul protocollo 802.15.4, tale standard specifica
una serie di profili applicativi che
permettono di realizzare una
comunicazione specifica tra diversi dispositivi che variano dal
mondo dell’energia (Smart
Energy) al mondo della

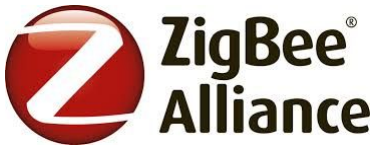
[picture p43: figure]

domotica (Home Automation e ZigbeeLightLink).
ZigBee opera nelle frequenze radio assegnate per scopi industriali, scientifici e medici (ISM, 868 MHz in Europa, 915 MHz negli Stati Uniti e 2,4

GHz nella maggior parte del resto del mondo), ma di fatto ad oggi le uniche vere implementazioni disponibile sul mercato sono quelle a 2,4 GHz. Questa tecnologia è nata con lo scopo di essere più semplice e più economica di altre Wireless PAN come, ad esempio il Bluetooth.
I protocolli ZigBee sono progettati per l'uso in applicazioni embedded che richiedano un basso transfer rate e bassi consumi. L'obiettivo di ZigBee è di definire una Wireless mesh network non mirata, economica e autogestita che possa essere utilizzata per scopi quali il controllo industriale, le reti di sensori, domotica, le telecomunicazioni, ecc. La rete risultante avrà un consumo energetico talmente basso da poter funzionare per uno o due anni sfruttando la batteria incorporata nei singoli nodi.
Ci sono tre differenti tipi di dispositivo ZigBee:
- ZigBee Coordinator (ZC): è il dispositivo più "intelligente" tra quelli disponibili, costituisce la radice di una rete ZigBee e può operare da ponte tra più reti. Ci può essere un solo "Coordinator" in ogni rete. Esso è inoltre in grado di memorizzare informazioni riguardo alla sua rete e può agire come deposito per le chiavi di sicurezza.
- ZigBee Router (ZR): questi dispositivi agiscono come router intermedi passando i dati da e verso altri dispositivi. Di fatto non vi sono distinzioni hardware tra un ZC e un ZR se non che viene rilasciato al coordinator il ruolo di inizializzare la rete, dopodiché diventano dispositivi identici.
- ZigBee End Device (ZED): includono solo le funzionalità minime per dialogare con il nodo padre (Coordinator o Router), non possono trasmettere dati provenienti da altri dispositivi e dunque non partecipano al multi-hop di un messaggio; sono i nodi che richiedono il minor quantitativo di memoria e quindi risultano spesso più economici rispetto ai ZR o ai ZC.

### Le Reti BAN

Le Body Area Network (BAN) o Body Sensor Network (BSN), anche chiamate Wireless Body Area Network (WBAN), sono reti che interconnettono dispositivi indossabili, il cui raggio di copertura è inferiore ad un metro. La rete BAN permette il passaggio di comunicazione attraverso segnale elettrico o luminoso a seconda del link di comunicazione utilizzato. Le applicazioni più tipiche sono le reti di sensori corporei in campo biomedico.

## Reti IR

Come specificato in precedenza, nel nostro progetto, oltre ad aver interagito con una rete WLAN abbiamo avuto a che fare anche con una rete generata da dispositivi ottici quali i
LED infrarossi. Muniti di Trasmettitori IR | e Ricevitori IR abbiamo generato una rete nella
quale identifichiamo il nodo “Master”, il nodo1 | che è slave per il “Master” | e master per il
nodo2 e il nodo2 | che è slave per il nodo1. Quella che abbiamo creato è una rete
peer-to-peer | vista la natura dei nodi, questi infatti comunicano tra di loro senza aver
bisogno di un AP | che ‘smista’ le informazioni e le passa a chi di dovere.
Un esempio pratico lo notiamo nella comunicazione di attivazione di un attuatore presente nel nodo 2, infatti in questo caso il ‘Master’ riceve le informazioni su quale attuatore attivare direttamente dal device in questione (PC, tablet, smartphone) poi elabora tali dati e invia la richiesta al nodo1, il nodo1 elabora il dato controllando se è un’informazione per attivare un suo attuatore o meno, essendo per il nodo2 come da ipotesi il nodo1 invia a sua volta il dato al nodo2 il quale lo elabora, comprende che è un dato per lui (se non è corrotto, altrimenti interrompe la comunicazione comunicandolo al nodo1 e il nodo1 al ‘Master’ ) comunica al nodo1 che il dato è buono, il nodo 1 rimasto in ascolto riceve l’ACK e a sua volta invia l’ACK al ‘Master’ che aggiorna la pagina HTML.
Come possiamo notare la comunicazione è indipendente tra nodo e nodo, non ci sono intermediari, le informazioni passano direttamente da un nodo all’altro.
la radiazione infrarossa (IR) è la radiazione elettromagnetica con banda di frequenza dello spettro elettromagnetico inferiore a quella della luce visibile, ma maggiore di quella delle onde radio, ovvero lunghezza d'onda compresa tra 700 nm e 1 mm (banda infrarossa). Il termine significa "sotto il rosso" (dal latino infra, "sotto"), perché il rosso è il colore visibile con la frequenza più bassa. Viene spesso associata con i concetti di "calore" e "radiazione termica", poiché ogni oggetto con temperatura superiore allo zero assoluto (in pratica qualsiasi oggetto reale) emette spontaneamente radiazione in questa banda. La radiazione infrarossa viene usata in apparecchi di visione notturna, quando non c'è abbastanza luce visibile e in commercio ci sono due classi di telecamere ad Infrarosso: le prime sono generalmente sensibili sia all'infrarosso vicino e alla luce visibile e non permettono la misurazione della temperatura vengono generalmente chiamate telecamere IR (o Day & Night), le seconde sono sensibili all'infrarosso medio (termico) e sono definite termocamere.
L'infrarosso è utilizzato anche come mezzo di trasmissione dati: nei telecomandi dei televisori (per evitare interferenze con le onde radio del segnale televisivo), tra computer portatili e fissi, palmari, telefoni cellulari, nei sensori di movimento e altri apparecchi elettronici.

Lo standard di trasmissione dati affermato è l’IrDA (Infrared Data Association). Telecomandi e apparecchi IrDA usano diodi emettitori di radiazione infrarossa (comunemente detti LED infrarossi). La radiazione infrarossa da essi emessa viene messa a fuoco da lenti di plastica e modulata, cioè accesa e spenta molto rapidamente, per trasportare dati. Il ricevitore usa un fotodiodo al silicio per convertire la radiazione infrarossa incidente in corrente elettrica. Risponde solo al segnale rapidamente pulsante del trasmettitore, ed è capace di filtrare via segnali infrarossi che cambiano più lentamente come luce in arrivo dal Sole, da altri oggetti caldi, e così via.
Anche la luce usata nelle fibre ottiche è spesso infrarossa.

### L’IrDA

L’IrDa (Infrared Data Association) è un’organizzazione no profit di produttori elettronici che vanno a definire, regolamentare e ratificare le regole o i protocolli che stanno alla base delle comunicazioni che fanno uso della radiazione infrarossa. Comunicazioni di questo tipo vengono definite wireless (senza fili) e vengono adoperate nelle brevi distanze.
I protocolli definiti sono i seguenti:

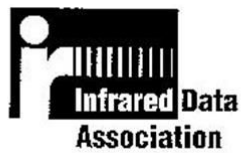
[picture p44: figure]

PROTOCOLLI | DESCRIZIONE

IrPHY (Infrared Physical Layer Specification)

Costituisce il livello più basso delle specifiche IrDA. Caratterizzato dal fatto che la distanza di trasmissione non può essere maggiore di 1m nel caso standard, 0.3m a basso consumo e 0.2 tra due device a basso consumo, impone che l’angolo di trasmissione determini un cono minimo di +-15°; la velocità di trasf. varia tra i 2.4 kbit/s a 16 Mbit/s e dispone di una finestra a infrarossi. Definiamo 4 modalità fondamentali di trasmissione: SIR o serial infrared con velocità di trasmissione di 9600 bit/s . MIR o medium infrared e presenta velocita tra 0.576 Mbit/s e 1.152 Mbit/s. FIR o fast infrared (obsoleto) e velocità di trasmissione di 4 Mbit/s. VFIR o Vary Fast Infrared con transfer-rate di 16 Mbit/s.

IrLAP (Infrared Link Access Protocol)

Rappresenta il livello datalink del modello ISO/OSI. Le sue specifiche più importanti sono: l’autenticazione, il rilevamento di altri dispositivi di comunicazione IrDA, lo stabilimento di una connessione bidirezionale, la negoziazione del ruolo dei dispositivi che sono suddivisi tra un dispositivo primario, che controlla e abilita o meno gli altri dispositivi al trasferimento, e uno o più dispositivi secondari dipendenti da quello primario.

IrLMP (Infrared Link Management Protocol) | È un protocollo obbligatorio ed è distinto in due parti. LM-MUX (Link Management Multiplexer), situato sopra il livello IrLAP, provvede alla creazione di canali logici multipli per la trasmissione del flusso di dati, e permette lo scambio tra dispositivo primario e dispositivi secondari. La seconda parte del protocollo, LM-IAS (Link Management Information Access Service) fornisce un registro di servizi integrabile e accessibile tramite query.
Tiny TP (Tiny Transport Protocol) | Protocollo opzionale che provvede al trasferimento di file i quali vengono suddivisi in pacchetti di ridotte dimensioni (per migliorare la velocità di trasmissione e ridurre la perdita di dati) che il ricevitore assembla tra loro ricostruendo il file originario e provvede al controllo di flusso dei dati assegnando le priorità ad ogni canale logico.
IrCOMM (Infrared Communications Protocol) | Protocollo opzionale che permette ad un dispositivo infrarossi di agire come una porta seriale o parallela.
IrOBEX (Infrared Object Exchange) | Protocollo opzionale che permette lo scambio di oggetti dati tra dispositivi.
IrLAN (Infrared Local Area Network) | protocollo opzionale che permette di connettere un dispositivo a raggi infrarossi con una rete locale in tre modi: ● Access Point ● Peer-to-peer ● Host Si posiziona sopra il protocollo Tiny TP che è quindi necessario abilitare per il funzionamento di IrLAN.
IrSimple | IrSimple migliora l'efficienza del protocollo di trasmissione aumentandone la velocità da 4 a 10 volte pur mantenendo la retrocompatibilità con i protocolli IrDA precedenti.
IrFM(Infrared financial messaging) | protocollo opzionale per effettuare transazioni finanziarie tramite un dispositivo a infrarossi.

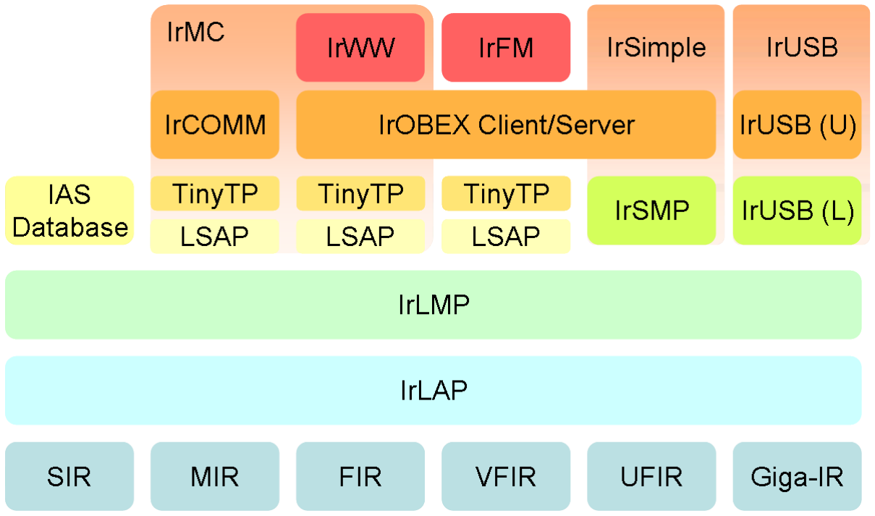
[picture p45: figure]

IrDA permette la creazione di reti di tipo PAN ed è uno standard diffuso globalmente. È largamente adottato su computer portatili, palmari, cellulari.
Il bluetooth, che è uno standard di trasmissione radio, ha tuttavia soppiantato la trasmissione a infrarossi su alcuni dispositivi.
I dispositivi a infrarossi, per funzionare correttamente, devono essere posizionati in condizioni di visibilità reciproca (la cosiddetta LoS, Line of Sight, linea di vista) ad una distanza di 1 o 2 metri. Questi limiti dipendono dal fatto che la radiazione infrarossa prodotta da questi dispositivi non è in grado di attraversare muri o altre barriere solide significative (anche il vetro di una finestra può pregiudicare la qualità della trasmissione). La velocità di trasmissione più comune è di circa 4 Mbit/s, ma alcuni dispositivi raggiungono i 16 Mbit/s.

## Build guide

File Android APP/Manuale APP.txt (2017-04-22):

-----------------------MANUALE APP------------------------

VERSIONE 1.0
DATA: APRILE 2017

___________________________________________________________

PIETRO RIGNANESE & ANDREA POLENTA

___________________________________________________________

L'applicazione si presenta in modo molto semplice ed è 
suddivisa in tre schermate:
	1. Schermata principale(HOME)
	2. Schermata di controllo dello stato
	3. Schermata per il controllo in remoto

SCHERMATA PRINCIPALE---------------------------------------

la schermata principale è formata da soli 2 bottoni
per spostarsi nell'app.
Il primo bottone rappresenta un occhio per spostarsi
nella schermata di controllo dello stato.
Mentre il secondo bottone, a forma di joypad, rappresenta
la seconda schermata.

------------------------------------------------------------

SCHERMATA DI CONTROLLO DELLO STATO--------------------------

La schermata e suddivisa in tre parti:
1. Nodo master
2. Nodo 1
3. Nodo 2

In ogni parte sono riportati i dispositivi collegati a quel 
nodo e il loro stato.

la connessione avviene attraverso un database
Firebase: https://www.firebase.google.com/

-------------------------------------------------------------

SCHERMATA DI CONTROLLO IN REMOTO-----------------------------

-------------------------------------------------------------

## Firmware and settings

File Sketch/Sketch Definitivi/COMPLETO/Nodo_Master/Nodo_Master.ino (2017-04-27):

//---------------------------------------------------------CALCOLATORI ELETTRONICI E RETE DI CALCOLATORI---------------------------------------------------------

//-------------------------------------------------------------PIETRO RIGNANESE & ANDREA POLENTA  2017----------------------------------------------------------- 

/* Programma da mandare sulla shield wi-fi ESP8266 ESP-12E.
 *  Questo programma instaura prima di tutto una connessione wi-fi ad una rete WLAN locale
 *  e comunica sia con il dispositivo connesso e allocato all'indirizzo IP della shield sia con gli altri nodi
 *  adiacenti attraverso la connessione ottica.
 *  La pagina HTML che sarà mandata al client presenta diversi radio button per far comunicare
 *  i cambiamenti dei dispositivi posti sui nodi dal Nodo Master.
 *  Il Nodo Master è l'unico nodo che è connesso alla rete domestica ed è a capo del ponte di nodi.
 *  Da lui passano tutti i dati(andata e ritorno che siano).
 *  
 *  La relazione del seguente progetto è presente su GitHub a questo link:
 *  https://github.com/domoticawifi/Network-nodes
 *  
 *  Strumenti > Scheda: > Mode MCU 1.0
 *  Struemnti > Porta > COM
 *  
 *  COLLEGAMENTI:
 *  PIN D0 -> EMETTITORE LED IR
 *  PIN D1 -> DISPLAY
 *  PIN D2 -> DISPLAY
 *  PIN D3 -> RICEVITORE IR
 *  PIN D4 -> RELE'
 *  
 *  Per domande, informazioni o altro contattateci sui social
 *  Pietro Rignanese (Manfredonia - Italy - Stedente UNIVPM)
 *  Andrea Polente  (Montecassiano - Italy - Studente UNIVPM)
 *  
 *  oppure alle mail:
 *      
 *      orteip_94@live.it
 *      pietro_rignanese@hotmail.it
 *      poly94.ap@gmail.com
 *      
 *      NETWORK-NODES
 *      
 *      2017 Universitrà politecnica delle Marche
 *      
 *      DATA ULTIMA MODIFICA: SABATO 22 APRILE 2017 ORE 16:01
 *      
 *      */

// Inclusione dell'apposita libreria per la Shield adoperata
#include <ESP8266WiFi.h>
// Libreria di gestione infrarossi per la shield esp8266
#include <IRremoteESP8266.h>

//Libreria per database esterno (Firebase)
#include <FirebaseArduino.h>
//Credenziali di accesso al database
#define FIREBASE_HOST "sentinel-83e9f.firebaseio.com"
#define FIREBASE_AUTH "W7F3oHDG85MScrN0XiDnrCKbNGEBnrRf6DSffiul"

//Librerie per gestione display
#include <Wire.h> 
#include <LiquidCrystal_I2C.h>

//Definizione delle credenziali per la connessione per accedere al Router
const char* ssid = "****";
const char* password = "****";

//Variabile contenente l'indirizzo IP assegnato alla shield ESP-12E
String IP = "";

// Definiamo la mappatura della Shield ESP8266(Datasheet)
#define D0 16 // Trasmettitore IR
#define D1 5  // Display
#define D2 4  // LCD
#define D3 0  // Ricevitore IR 
#define D4 2  // Relè
#define D5 14 
#define D6 12 
#define D7 13
#define D8 15
#define D9 3  // RX
#define D10 1 // TX

//Istanziamo le variabii di Controllo Invio/Ricezione
boolean controllo_invio = true;
boolean controllo_ricezione = true;

//Istanziamo un flag per verificare lo stato della connessione
//Verifichiamo se la connessione è la ricezione del messaggio di ACK è avvenuta senza problemi
boolean stato_conn = true;

// Istanziamo 'server(80)' come oggetto della classe WiFiServer.
WiFiServer server(80);

//Istanziamento display
LiquidCrystal_I2C lcd(0x27,20,4); 

IRsend irsend(D0); //Instanziamo un oggetto per la trasmissione dell'informazione tramite IR al pin D0
IRrecv irrecv(D3); //Instanziamo oggetto per ricezione segnale infrarosso
decode_results results;

void setup() 
{
  //Display
  lcd.init();                     
  lcd.backlight();

  // Instanziamo la comunicazione infrarossi
  irsend.begin();
  irrecv.enableIRIn();
  
  // Connessione seriale a 115200.
  Serial.begin(115200);
  delay(10);

  // Inizializziamo i dispositivi connessi al nodo allo stato di LOW
  pinMode(D4, OUTPUT);
  digitalWrite(D4, LOW);

  Serial.println("------------------NODO MASTER-------------");
  Serial.println("");

  //Stampiamo il benvenuto sul display appena la scheda sarà accesa
  lcd.home();
  lcd.print("Benvenuto!");
  delay(2500);
  lcd.setCursor(0, 0);
  lcd.print("Inizializzazione");
  lcd.setCursor(0,1);

  //Connessione alla rete WiFi
  // Mostriamo l'IP della scheda connessa alla rete
  Serial.print("\n\nInizializzazione rete WiFi: ");
  Serial.println(ssid);
  WiFi.begin(ssid, password);
  while (WiFi.status() != WL_CONNECTED) {
    delay(500);
    Serial.print(".");
    lcd.print(".");
  }
  lcd.setCursor(0,0);
  Serial.println("\nConnesso!");
  lcd.print("Connesso        ");
  Serial.print("IP del dispositivo: ");
  Serial.print(WiFi.localIP());
  lcd.setCursor(0,1);
  lcd.print(WiFi.localIP());

  // Inizializziamo il WebServer.
  server.begin();
  Serial.println("\nWebServer inizializzato.\n");

  Firebase.begin(FIREBASE_HOST, FIREBASE_AUTH); //Inizializza firebase
}
//Variabile contatore per verificare il tempo di attesa dell'invio del messaggio fino alla ricezione dell'ACK
int i = 0;

//Funzione per la comunicazione tra Nodo Master e Nodo 1 durante l'invio del dato
void comunicazione()
{  
  Serial.println("Comunicazione");
  do
  {
    //Viene controllato, attraverso il sensore IR, se viene ricevuto un dato
    if(irrecv.decode(&results))
      {
        //Ricezione avvenuta!
        
        Serial.println("Dato ricevuto:");
        Serial.println(results.value);

        //Dato ricevuto correttamente
        if(results.value == 4369)
        {
          lcd.setCursor(0,0);
          lcd.print("      ACK       ");
          lcd.setCursor(0,1);
          lcd.print("      O K       ");
          controllo_ricezione = false;
          controllo_invio = false;
          stato_conn = true;
          Serial.println("Dato valido");
          delay(10000);        
        }
        //Dato non ricevuto correttamente
        else
        {
          controllo_ricezione = false;
          stato_conn = false;
          Serial.println("Dato non valido");
        }
      }
     delay(1);
     Serial.print(i++);
     controllo_ricezione = false;

      //Attesa di 10000 milli secondi = 10 secondi, dopo di che chiude la connessione
     if(i == 10000)
     {
       Serial.println("Connessione scaduta");
       controllo_ricezione = false;
       controllo_invio = false;
       stato_conn = false;
     }
     irrecv.resume(); //Ricevi un altro valore
     
  }while(controllo_ricezione);
  Serial.println("Sono uscito... ");
  
}

  int RM = LOW;   // Relè nodo master
  int RN1 = LOW;  // Relè Nodo 1
  int AN1 = LOW;  // Attuatore Nodo 1
  int RN2 = LOW;  // Relè Nodo 2
  int AN2 = LOW;  // Attuatore Nodo 2

//Variabili di controllo per il cambiamento di stato effettuato
//Quando le variabili sono a TRUE il cambiamento è avvenuto mentre a FALSE il cambiamento potrebbe non essere stato effettuato
  boolean CRN1 = true;
  boolean CAN1 = true;
  boolean CRN2 = true;
  boolean CAN2 = true;

  WiFiClient cliente;

  String percorso = "NetworkNodes/"; //Stringa che conterrà il percorso del database firebase

//Funzione che aggiorna il database Firebase
void firebase_upload(String nodo, String dispositivo, String stato)
{
  percorso = "NetworkNodes/";
  // rimozione valore precedente
  percorso += nodo;
  percorso += dispositivo;
  Firebase.remove(percorso);

  // settaggio valore attuale
  Firebase.setString(percorso, stato);
  // Errore connessione
  if (Firebase.failed()) {
      Serial.print("setting /message failed:");
      Serial.println(Firebase.error());  
      return;
  }
}

boolean js = false; //Variabile per far partire o meno la modifica della pagina di errore
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
void loop() 
{  
  i=0;  //Settaggio a zero della variabile che conta il tempo di attesa
    
  // Vediamo se esiste una connessione con un client. Se non esiste ritorniamo al loop.
  cliente = server.available();
  if (!cliente) 
  {
    //Se la connessione al client non è presente, il Nodo Master è in ascolto verso il Nodo 1 per la ricezione 
    //del dato analogico attraverso pulsante
    if(irrecv.decode(&results))
    {
      Serial.println(results.value);
      if(results.value==4112)
      {
        RN1=HIGH;
        change_state_rn1_on = false;
        change_state_rn1_off = true;
        analogic_input = true;
      }
      if(results.value==257)
      {
        RN1=LOW;
        change_state_rn1_on = true;
        change_state_rn1_off = false;
        analogic_input = true;
      }
      if(results.value==1118481)
      {
        AN1=HIGH;
        change_state_an1_on = false;
        change_state_an1_off = true;
        analogic_input = true;
      }
      if(results.value==1052688)
      {
        AN1=LOW;
        change_state_an1_off = false;
        change_state_an1_on = true;
        analogic_input = true;
      }
      irrecv.resume();
      
    }
    return;
  }

  // Nela caso ci sia una connessione con un client, mostriamo un messaggio di avvenuta connessione
  // mantenendo aperta la connessione.
  Serial.println("Client connesso: ");
  while (!cliente.available()) 
  {
    delay(1);
  }

  String form ="";  //Stringa contenente l'indirizzo IP, e eventuale form, del Nodo Master

  //Controllo per vedere se l'input è avvenuto per via analogica o tramite device
  if(analogic_input)
  {
    form = "http://";
    form += IP;
  }
  else
  {
    //Realizziamo la lettura della form.
    form = cliente.readStringUntil('\r');
  }

  analogic_input = false; //Resettiamo la variabile del controllo dell'input analogico
  
  Serial.println(form);
  cliente.flush();

// Controllo della from restituita dall'aggiornamento della pagina HTML
  if(form.indexOf("RelayMaster=ON")!=-1)
    {
      lcd.setCursor(0,0);
      lcd.print("Relay ON        ");
      lcd.setCursor(0,1);
      lcd.print("Attendere...    ");
      delay(100);
      digitalWrite(D4, HIGH); // Accensione Relè nodo master
      RM = HIGH;
    }
  if(form.indexOf("RelayMaster=OFF")!=-1)
    {
      lcd.setCursor(0,0);
      lcd.print("Relay OFF       ");
      lcd.setCursor(0,1);
      lcd.print("Attendere...    ");
      delay(100);
      digitalWrite(D4, LOW);  // Spegnimento relè nodo master
      RM = LOW;
    }

    //-----------------------------------------------NODO 1---------------------------------------
    if(form.indexOf("Relay1=ON")!=-1)
    {
      lcd.setCursor(0,0);
      lcd.print("Relay Nodo1 ON  ");
      lcd.setCursor(0,1);
      lcd.print("Attendere...    ");
      delay(100);
      Serial.println("ACCENSIONE RELAY NODO 1");
      
      if(change_state_rn1_on)
      
      {
        change_state_rn1_on  = false;
        change_state_rn1_off = true;
        do
        {
          //Controllo tempo di attesa
          if(i<1000)
          {
            irsend.sendNEC(0x0000000001, 32); //Invio dato al nodo 1 per l'accensione del relè nodo 1
            comunicazione();
            i++;  //Aumenta di +1 il tempo di attesa
          }
          else
          {
            controllo_invio = false;
          }
         }while(controllo_invio);
        
        Serial.println("Anch'io...");
        //Controllo stato connessione per modificare o meno la pagina HTML
        if(stato_conn)
        {
          RN1 = HIGH;
          CRN1 = true;
        }
        else
        {
          RN1 = LOW;
          js = true;
          CRN1 = false;
        }
        //Resetto le variabili di controllo per una prossima comunicazione
        stato_conn = true;
        controllo_invio=true;
        controllo_ricezione=true;
        i=0;      
      }
      
    }
    
  if(form.indexOf("Relay1=OFF")!=-1)
    {
      lcd.setCursor(0,0);
      lcd.print("Relay Nodo1 OFF ");
      lcd.setCursor(0,1);
      lcd.print("Attendere...    ");
      delay(100);
      Serial.println("SPEGNIMENTO RELAY NODO 1");
      if(change_state_rn1_off)
      
      {
        change_state_rn1_off = false;
        change_state_rn1_on = true;
        do
        {
          if(i<1000)
          {
            irsend.sendNEC(0x0000000101, 32); // Invio dato al nodo 1 per lo spegnimento del relè nodo 1
            comunicazione();
            i++;
          }
          else
          {
            controllo_invio = false;
          }
         }while(controllo_invio);
        
        Serial.println("Anch'io...");
        //Controllo stato connessione per modificare o meno la pagina HTML
        if(stato_conn)
        {
          RN1 = LOW;
          CRN1 = true;
        }
        else
        {
          RN1 = HIGH;
          js = true;
          CRN1 = false;
        }
        //Resetto le variabili di controllo per una prossima comunicazione
        stato_conn = true;
        controllo_invio=true;
        controllo_ricezione=true;
        i=0;
      }
      
    }
  if(form.indexOf("Attuatore1=ON")!=-1)
    {
      lcd.setCursor(0,0);
      lcd.print("Attuat. Nodo1 ON");
      lcd.setCursor(0,1);
      lcd.print("Attendere...    ");
      delay(100);
      Serial.println("ACCENSIONE ATTUATORE NODO 2");
      if(change_state_an1_on)
      
      {
        change_state_an1_on = false;
        change_state_an1_off = true;
        do
        {
          if(i<1000)
          {
            irsend.sendNEC(0x0000000011, 32); //Invio dato al nodo 1 per l'accensione dell'attuatore nodo 1
            comunicazione();
            i++;
          }
          else
          {
            controllo_invio = false;
          }
         }while(controllo_invio);
        
        Serial.println("Anch'io...");
        //Controllo stato connessione per modificare o meno la pagina HTML
        if(stato_conn)
        {
          AN1 = HIGH;
          CAN1 = true;
        }
        else
        {
          AN1 = LOW;
          js = true;
          CAN1 = false;
        }
        //Resetto le variabili di controllo per una prossima comunicazione
        stato_conn = true;
        controllo_invio=true;
        controllo_ricezione=true;
        i=0;
        }
      
    }
  if(form.indexOf("Attuatore1=OFF")!=-1)
    {
      lcd.setCursor(0,0);
      lcd.print("Attua. Nodo1 OFF");
      lcd.setCursor(0,1);
      lcd.print("Attendere...    ");
      delay(100);
      Serial.println("SPEGNIMENTO ATTUATORE NODO 1");
      if(change_state_an1_off)
      
      {
        change_state_an1_off = false;
        change_state_an1_on = true;
        do
        {
          if(i<1000)
          {
            irsend.sendNEC(0x0000000010, 32); // Invio dato al nodo 1 per lo spegnimento dell'attuatore nodo 1
            comunicazione();
            i++;
          }
          else
          {
            controllo_invio = false;
          }
         }while(controllo_invio);
        
        Serial.println("Anch'io...");
        //Controllo stato connessione per modificare o meno la pagina HTML
        if(stato_conn)
        {
          AN1 = LOW;
          CAN1 = true;
        }
        else
        {
          AN1 = HIGH;
          js = true;
          CAN1 = false;
        }
        //Resetto le variabili di controllo per una prossima comunicazione
        stato_conn = true;
        controllo_invio=true;
        controllo_ricezione=true;
        i=0;
      }
      
    }
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

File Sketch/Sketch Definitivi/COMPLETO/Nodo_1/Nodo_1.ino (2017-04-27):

//---------------------------------CALCOLATORI ELETTRONICI E RETE DI CALCOLATORI-------------------------------------------//

//------------------------------------PIETRO RIGNANESE & ANDREA POLENTA   2017------------------------------------------------------//

/*
 * 
 * NODO 1
 * 
 * Link Progetto: https://github.com/domoticawifi/Network-nodes
 * 
 * Strumenti > Scheda: > Arduino UNO/NANO
 * Strumenti > Porta > COM
 * 
 * Collegamenti:
 * PIN 2  -> Relè
 * PIN 3  -> Emettitore LED Infrared
 * PIN 4  -> Attuatore
 * PIN 8  -> Ricevitore IR
 * PIN 10 -> Pulsante Relè
 * PIN 11 -> Pulsante Attuatore
 * PIN A4 -> Display 
 * PIN A5 -> Display
 * 
 * Contatti:
 * 
 *  orteip_94@live.it
 *  pietro_rignanese@hotmail.it
 *  poly94.ap@gmail.com
 *  
 *  DATA ULTIMA MODIFICA: SABATO 22 APRILE 2017 ORA: 15:24
 */

//Librerie per gestione display
#include <Wire.h> 
#include <LiquidCrystal_I2C.h>

//Libreria per comunicazione IR
#include <IRremote.h>
int RECV_IR = 8;
IRrecv irrecv(RECV_IR);   //Ricezione del segnale IR sul pin 8
decode_results results;
IRsend irsend;

LiquidCrystal_I2C lcd(0x27,20,4);

int cont = 0; //Contatore per il conteggio dei secondi una volta ricevuto il dato dal Nodo Master
int num_ricezioni = 1; //Conteggio delle ricezioni

//Mappatura pin Arduino
int relay = 2;
int attuatore = 4;

//Variabili per controllare il pilotaggio dei pulsanti
boolean R = true;
boolean A = true;

boolean dato_corrotto = true;  //Flag per il controllo del dato corrotto

void setup() 
{ 
  pinMode(10,INPUT);  //Pulsante 1 = Relay
  pinMode(11,INPUT);  //Pulsante 2 = Attuatore
  
  //Display
  lcd.init();                     
  lcd.backlight();
  lcd.home();
  lcd.print("  --Nodo 1--  ");

  //Inizializzazione pin arduino
  pinMode(relay,OUTPUT);
  pinMode(attuatore, OUTPUT);
  
  Serial.begin(115200);
  Serial.println("------------------------------Nodo 1--------------------------");
  Serial.println("");
  
  irrecv.enableIRIn();        // Comincia la trasmissione del segnale  
}

//Funzione di risposta
void ack()
{
      cont = 0;
      delay(20);
      do
      {
        cont++;
        irsend.sendNEC(0x1000001111, 32);// invio del dato per la conferma della purezza del dato = 4369
        delay(20);
      }while(cont<80);
      
      //Reinstanziamento della ricezione
      irrecv.enableIRIn();
      irrecv.decode(&results);

      dato_corrotto = false;  //Pongo dato corrotto a false in modo da non richiedere l'invio del dato al Nodo Master
}

//Funzione per avvenuta ricezione del dato da parte del Nodo 2
boolean comunicazione()
{
  Serial.println("Sensore 2");
  int sec = 0;
  do
  {
     if (irrecv.decode(&results)) 
    {
      Serial.println(results.value);
      if(results.value == 4369)
      {
        lcd.setCursor(0,0);
        lcd.print("     ACK OK     ");
        lcd.setCursor(0,1);
        lcd.print("                ");
        Serial.println("OK");
        return true;
      }
      delay(1);
      sec++;
      irrecv.resume();
    
    }
  }while(sec<100);
  return false;
}

void loop() 
{
  //--------------------CONTROLLO ANALOGICO DEL NODO------------------------------
  
  if(digitalRead(10)==HIGH)
  {
    lcd.setCursor(0,0);
    lcd.print("  Pulsante 1");
    lcd.setCursor(0,1);
    lcd.print("                ");
    delay(100);
    if(R)
    {
      digitalWrite(relay,HIGH);
      R = false;
      irsend.sendNEC(0x1000001010, 32);// invio del dato per la conferma della purezza del dato = 4369
      delay(20);
      irrecv.enableIRIn();
      irrecv.decode(&results);
      Serial.println("ON Relay");
      delay(200);
    }
    else
    {
      digitalWrite(relay,LOW);
      R = true;
      irsend.sendNEC(0x1000000101, 32);// invio del dato per la conferma della purezza del dato = 4369
      delay(20);
      irrecv.enableIRIn();
      irrecv.decode(&results);
      Serial.println("OFF Relay");
      delay(200);
    }
    
  }
  if(digitalRead(11)==HIGH)
  {
    lcd.setCursor(0,0);
    lcd.print("  Pulsante 2");
    lcd.setCursor(0,1);
    lcd.print("                ");
    delay(100);
    if(A)
    {
      digitalWrite(attuatore,HIGH);
      A = false;
      irsend.sendNEC(0x1000111111, 32);// invio del dato per la conferma della purezza del dato = 4369
      delay(20);
      irrecv.enableIRIn();
      irrecv.decode(&results);
      Serial.println("ON Attua");
      delay(200);
    }
    else
    {
      digitalWrite(attuatore,LOW);
      A = true;
      irsend.sendNEC(0x1000101010, 32);// invio del dato per la conferma della purezza del dato = 4369
      delay(20);
      irrecv.enableIRIn();
      irrecv.decode(&results);
      Serial.println("OFF Attua");
      delay(200);
    }
  }

 //------------CONTROLLO AUTOMATIZZATO DEL NODO----------------
  
  
  //Controlla se è stato ricevuto un dato sul sensore IR
  if (irrecv.decode(&results)) 
  {
    dato_corrotto = true;
    Serial.println("");
    Serial.println("");
    Serial.println("Fase ");
    Serial.print(num_ricezioni);
    Serial.println("");
    Serial.println("Dato in arrivo...");
    Serial.println("");

    num_ricezioni++;
    
    lcd.setCursor(0,0);
    lcd.print("Comunicazione:");
    lcd.setCursor(0,1);
    
    Serial.println(results.value); //Stampa su terminale il valore del segnale ricevuto

    //-----------------Controllo del dato---------------------

    //Accensione Relay
    if(results.value == 1)
    {
      Serial.println("Accensione Relay");

      lcd.setCursor(0,1);
      lcd.print("Relay ON     ");
      digitalWrite(relay,HIGH);
      R = false;
      ack();
    }

    //Spegnimento Relay
    if(results.value == 257)
    {
      Serial.println("Segnimento Relay");
      lcd.setCursor(0,1);
      lcd.print("Relay OFF     ");
      digitalWrite(relay,LOW);
      R = true;
      ack();

      

      dato_corrotto = false;  //Pongo dato corrotto a false in modo da non richiedere l'invio del dato al Nodo Master
    }

    //Accensione Attuatore
    if(results.value == 17)
    {
      Serial.println("Accensione Attuatore");
      lcd.setCursor(0,1);
      lcd.print("Attuatore ON ");
      digitalWrite(attuatore,HIGH);
      A = false;
      ack();
    }

    //Spegnimento Attuatore
    if(results.value == 16)
    {
      Serial.println("Spegnimento Attuatore");
      lcd.setCursor(0,1);
      lcd.print("Attuatore OFF ");
      digitalWrite(attuatore,LOW);
      A = true;
      ack();
    }

    //Accensione Relay nodo 2
    if(results.value == 69632)
    {
      irsend.sendNEC(0x0000011000, 32);
      Serial.println("Accensione Relay 2");
      lcd.setCursor(0,1);
      lcd.print("Relay 2 ON ");

      //Reinstanziamento della ricezione
      irrecv.enableIRIn();
      irrecv.decode(&results);
      if(comunicazione())
      {
        ack();
      }

      dato_corrotto = false;  //Pongo dato corrotto a false in modo da non richiedere l'invio del dato al Nodo Master
  
    }
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
